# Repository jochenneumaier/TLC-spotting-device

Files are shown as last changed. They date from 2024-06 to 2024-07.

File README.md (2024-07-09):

# TLC-spotting-device
Fully Automated Spotting Device for Thin-Layer Chromatography based on the Modification of a 3D Printer



Column chromatography and the subsequent analysis of the collected fractions using thin-layer chromatography (TLC) are immensely popular and frequently used methods in organic chemistry. To analyze the fractions, they have to be spotted onto the TLC plates, which can be a time-consuming task. Therefore, we have developed an automatic spotting device based on a conversion of a 3D printer kit, which could be easily built for around 500 €. All parts come directly from the 3D printer kit, are 3D printed, or are commercially available, such as syringes and tubing. In this manuscript, we describe the design and use of the spotting device. In addition, we provide a detailed step-by-step assembly instruction and all CAD files for easy replication

The work was published in the Journal of Open Hardware and can be viewed here:

https://doi.org/10.5206/joh.v8i1.18995 

A demonstration video of the TLC spotting device

YouTube (https://www.youtube.com/watch?v=SJwV5dXgm_c)

A detailed assembly instructions can be downloaded here:

https://github.com/jochenneumaier/TLC-spotting-device/blob/c61a826025a51ef96ff2add6b32b9e10538b7a6b/ESI%20-%20Programmable%20Automatic%20Spotting%20Device.pdf

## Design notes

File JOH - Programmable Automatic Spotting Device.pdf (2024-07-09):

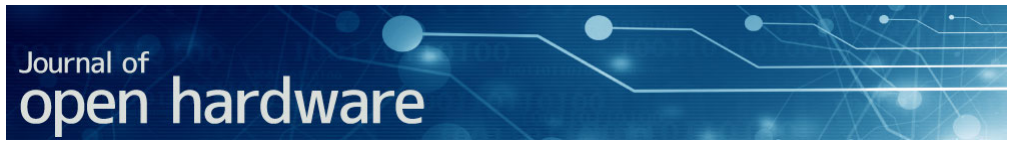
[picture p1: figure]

## Fully Automated Spotting Device for Thin-Layer Chromatography based on the Modification of a 3D Printer

1. Anna-Lena Renz (First author)
ORC ID: 0009-0005-1248-0691
Affiliation: University of Tuebingen, Auf der Morgenstelle 18, 72076 Tuebingen, Germany.
2. Florian Menzel
ORC ID: 0000-0002-1400-549X
Affiliation: Institute of Organic Chemistry, University of Tuebingen, Auf der Morgenstelle 18, 72076 Tuebingen, Germany.
3. Jochen M. Neumaier (corresponding author)
ORC ID: 0000-0002-7996-1490
Affiliation: Institute of Organic Chemistry, University of Tuebingen, Auf der Morgenstelle 18, 72076 Tuebingen, Germany.

## Abstract

Column chromatography and the subsequent analysis of the collected fractions using thin-layer chromatography (TLC) are immensely popular and frequently used methods in organic chemistry. To analyze the fractions, they have to be spotted onto the TLC plates, which can be a time-consuming task. Therefore, we have developed an automatic spotting device based on a conversion of a 3D printer kit, which could be easily built for around 500 €. All parts come directly from the 3D printer kit, are 3D printed, or are commercially available, such as syringes and tubing. In this manuscript, we describe the design and use of the spotting device. In addition, we provide a detailed step-by-step assembly instruction and all CAD files for easy replication.

## Metadata Overview

Main design files: https://doi.org/10.5281/zenodo.12517787
Target group: Scientists and technicians working in chemistry, biochemistry, and associated disciplines.
Skills required: 3D printing – easy; cutting with an angle grinder – easy; mechanical assembly – easy; G-code – easy; Excel usage – easy.
Replication: So far, no replicas have been known to the authors.
See section “Build Details” for more detail.

## Keywords

TLC Spotting; liquid handling; 3D printing; automation; G-code

# (1) Overview

## Introduction

Since thin-layer chromatography (TLC) is a quick, cheap, and sensitive chromatography technique with various post-chromatographic treatment options, it is routinely used in organic chemistry for reaction control and analysis of the fractions acquired after column chromatography.[1, 2] However, to examine the collected fractions a small sample of each fraction must be spotted onto a TLC plate. This task can be very time-consuming, especially as more and more fractions need to be analyzed.
Commercially available spotting devices are quite expensive and usually very inflexible in terms of the size of the rack and the TLC plate.[3] Particularly the usage of different rack sizes can be beneficial, as preparative column chromatography is performed with different amounts of substance and the fractions are collected in vials of different sizes. Therefore, different conditions require different rack sizes and different settings.[2, 3]
There are already several semi-automated and even fully automated devices developed for similar purposes.[4-12] However, most of these devices are designed more for liquid handling operations and do not meet our requirements for spotting TLC plates using flexible rack and TLC plate sizes.
In recent years, there have also been several projects in which low-cost 3D printers have been converted into scientific devices such as syringe pumps or HPLC fraction collectors.[13-16] This has the advantage that no programming or electronics knowledge is required, as the CNC motion control software of the 3D printer is used to control the devices.
We decided to develop a cost-effective, open hardware solution, based on an inexpensive 3D printer (Tronxy X5SA), that can be used with different rack types for TLC spotting. The system can be built for around 500 €. The Tronxy X5SA was chosen because its large print area of 330×330 mm provided the required flexibility for our application. It is also based on a core XY structure, which means that only the extruder moves in the X and Y directions, not the build plate which could have caused spilling. Using primarily the components of the Tronxy X5SA kit or 3D-printed parts, the assembly is fast and straightforward. The necessary G-code files can be easily generated with the attached Excel file, and it enables users to obtain the G-code for different rack sizes and user preferences.
The TLC robot was built to automate the spotting process but could also be used in other liquid handling tasks in the laboratory if the required sequence is programmed in G-code.

## Overall Implementation and Design

### Setup

The basic idea was to keep the assembly of the TLC robot as simple as possible so that anyone with basic manual skills could rebuild it. To achieve that, the design was kept as close to the 3D printer as possible, as can be seen in Figure 1. Originally it was considered to edit the firmware of the 3D printer to change the homing position, for example, but we decided to keep the approach as simple as possible and avoid programming tasks.

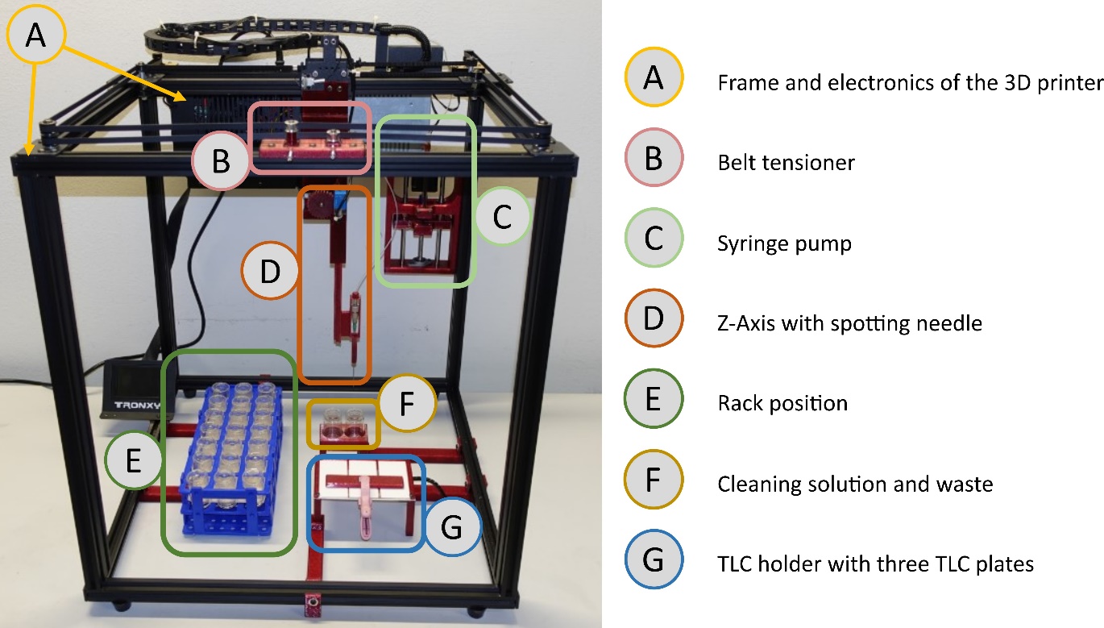
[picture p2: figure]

Figure 1: Overview of the Spotting Device.
Movement in the X and Y directions is ensured by the 3D printer's almost unchanged CoreXY system. Only a belt tensioner (B) has been added so that the tension can be adjusted after assembly. The movement of the capillary in Z-direction on the other hand is facilitated by a gear wheel and gear rack to which the cannula is attached (D). The syringe pump at the rear of the TLC robot (C) enables defined quantities of liquid to be dispensed.
To be able to clean the cannula, two glasses (diameter: 3 cm, height: 5 cm) are placed inside the table at the back (F), one filled with cleaning solution and one empty for the waste. The required number of TLC plates (4×8 cm) can be positioned on the TLC holder (G) and fixed with a clamp to maintain their position throughout the spotting process. The rack with the collected fractions (E) can be inserted on the left side. Its position is determined by aligning it with three positioners.
The various G-code programs can be created with the Excel file and stored on the SD card of the 3D printer. If the SD card is inserted into the Host box, the different programs can be selected on the display on the left side of the base frame.
As the system is modular, the different parts can easily be replaced with alternatives, allowing further customization. For example, the two tables can easily be replaced by slightly different variants if glasses or TLC plates with different dimensions are used.

### Motion in Z-Direction

In order to avoid prolonging the spotting process unreasonably, the capillary should be able to move in Z-direction at approximately the same velocity as in X- and Y-direction. Initially, a design with one lead screw and two guide rails (similar to the design of the syringe pump) was considered. However, the maximum velocity achievable with this design proved to be too low during the test. Therefore, this approach was replaced by the current design consisting of a gear wheel connected to the shaft of one NEMA motor and a gear rack inside a guiding rail to achieve the required speed (Figure 2). The size of the gear wheel was adjusted so that the capillary could move safely above all objects during the homing process.

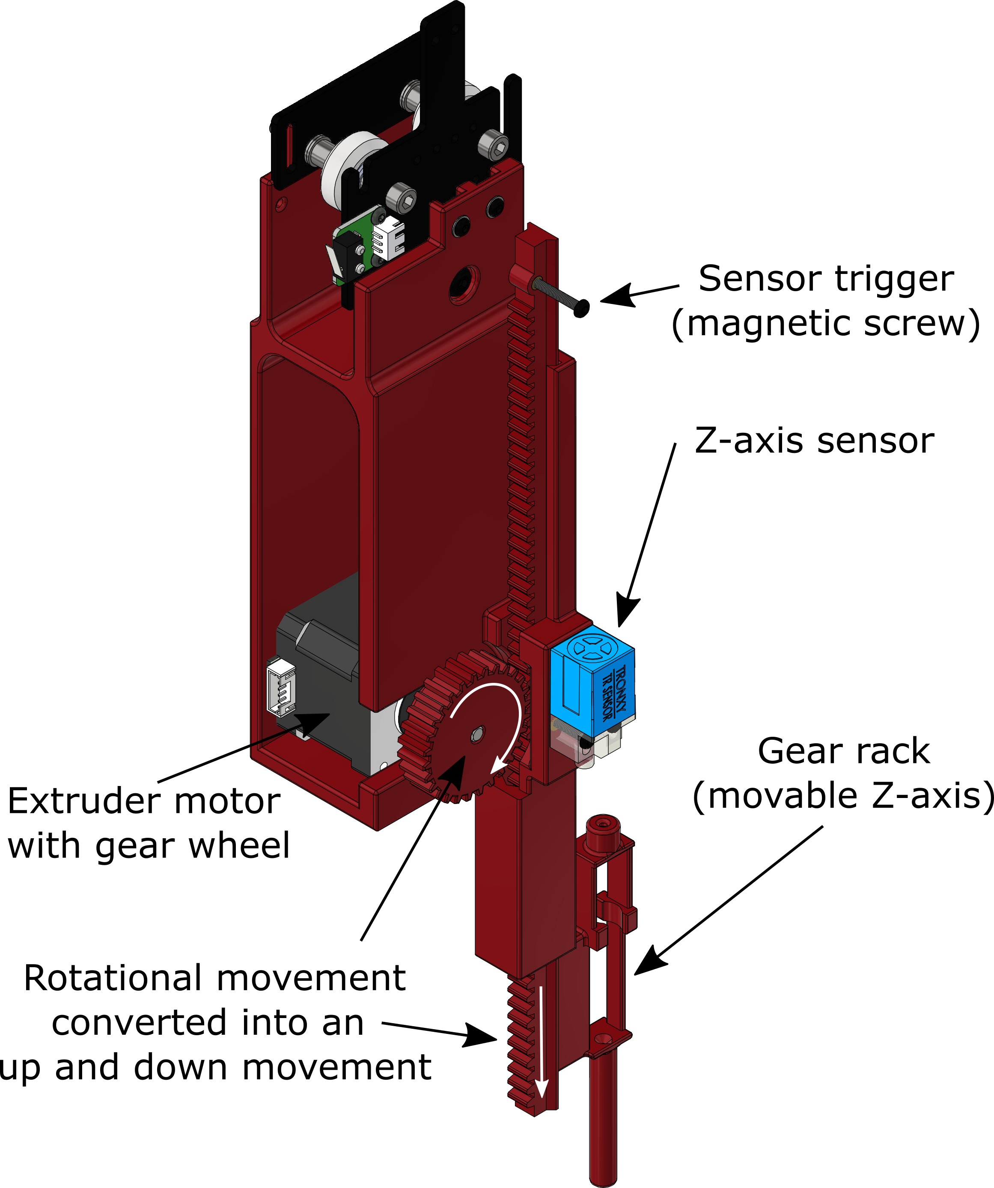
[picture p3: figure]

Figure 2: CAD drawing of the Z-axis mounting [17-20].

### Capillary Holder with Spring Mechanism

A standard medical cannula (Braun Sterican, 21G) was inserted into the rack, which represents the actual movable Z-axis (Figure 3). As the tip of the cannula must not be sharp, it was cut off and smoothed. A reasonably long capillary was used to ensure a long travel distance that is required to collect samples from vials with different fluid levels. To avoid the adhesion of a large fluid droplet to the outside of the cannula, a cannula with a small diameter (21G, 0.72mm) was used. As the cannula is in contact with the TLC plates during spotting, a spring mechanism was included to avoid scratching the surface of the TLC plates. This mechanism ensures that the cannula can move slightly upwards when it hits the TLC plate to provide even and gentle contact pressure and to compensate for any unevenness. The fixation was introduced to avoid rotation of the cannula. It is important to ensure that the connection with the fixation does not block the up- and downward movement of the cannula.

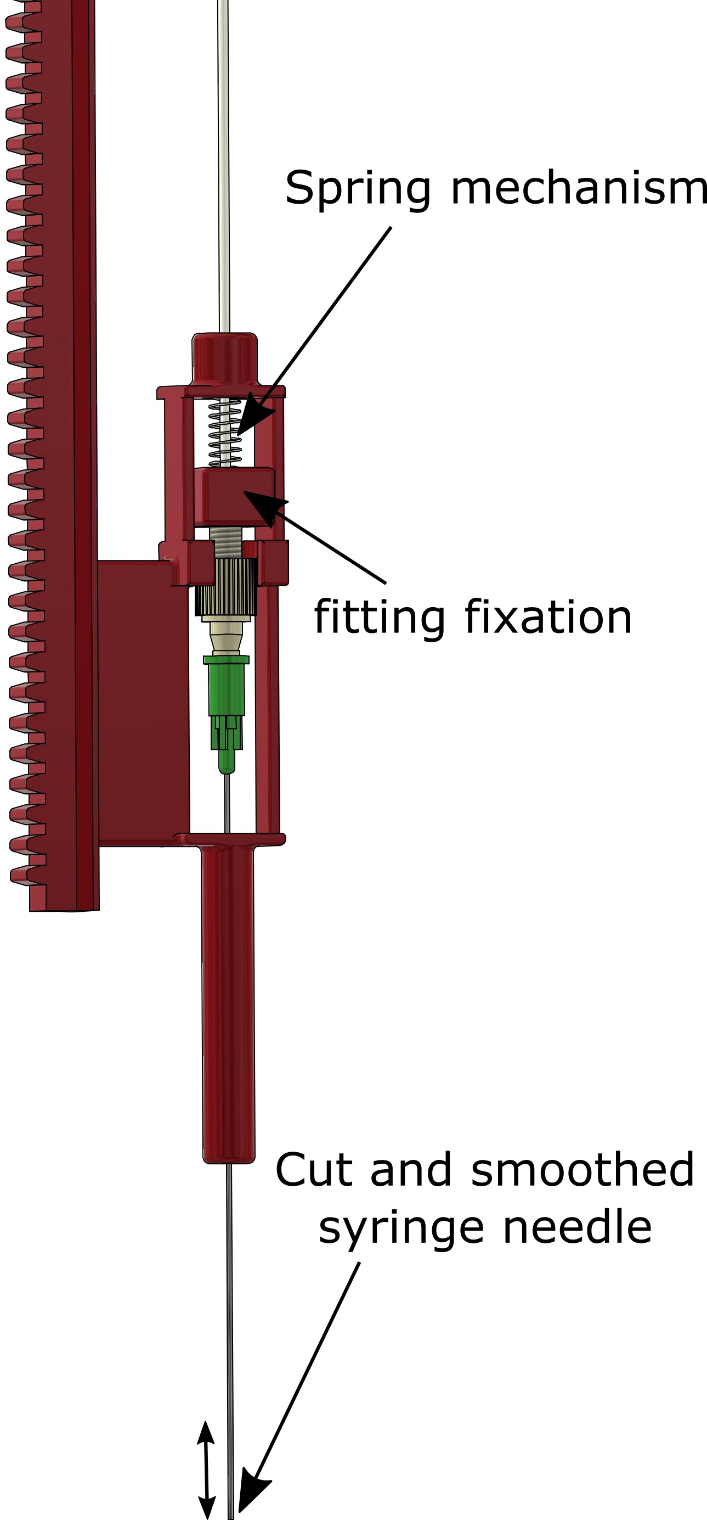
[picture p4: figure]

Figure 3: CAD drawing of the capillary holder with spring mechanism.

### Syringe Pump

The syringe pump was designed in a way that it is possible to collect and transport defined volumes from 1 µl to 1 mL. It is based on two guide rails and a lead screw (Figure 4), which both originally came from the 3D printer kit, and were shortened to the appropriate length (see ESI on Zenodo/GitHub). As syringe, a 1 mL Gastight Syringe (Model 1001 TLL from Hamilton) was chosen. The pump must be placed upright so that any air inclusions are expelled during the flushing process.

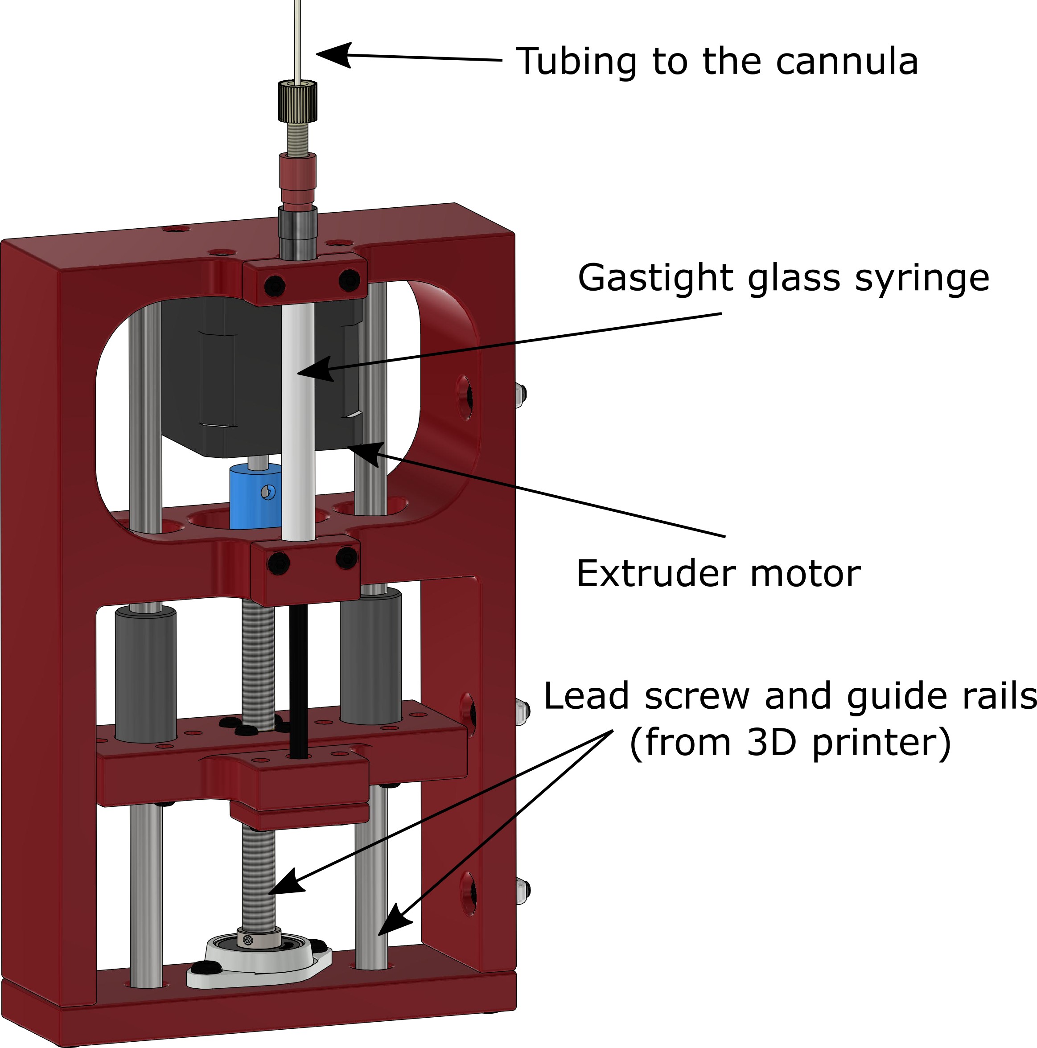
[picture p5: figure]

Figure 4: CAD drawing of the syringe pump.

### TLC Holder

To keep the TLC plates in place, a table based on an aluminium plate and a 3D-printed frame was used (Figure 5). As the size of our TLC plates (Machery Nagel POLYGRAM® SIL G/UV254, 40×80 mm) varied by 3 mm, a frame with small separators ensures that the plates remain in the same position during the spotting process. If larger TLC plates need to be used, the separators must either be cut off or removed in the CAD file before printing.

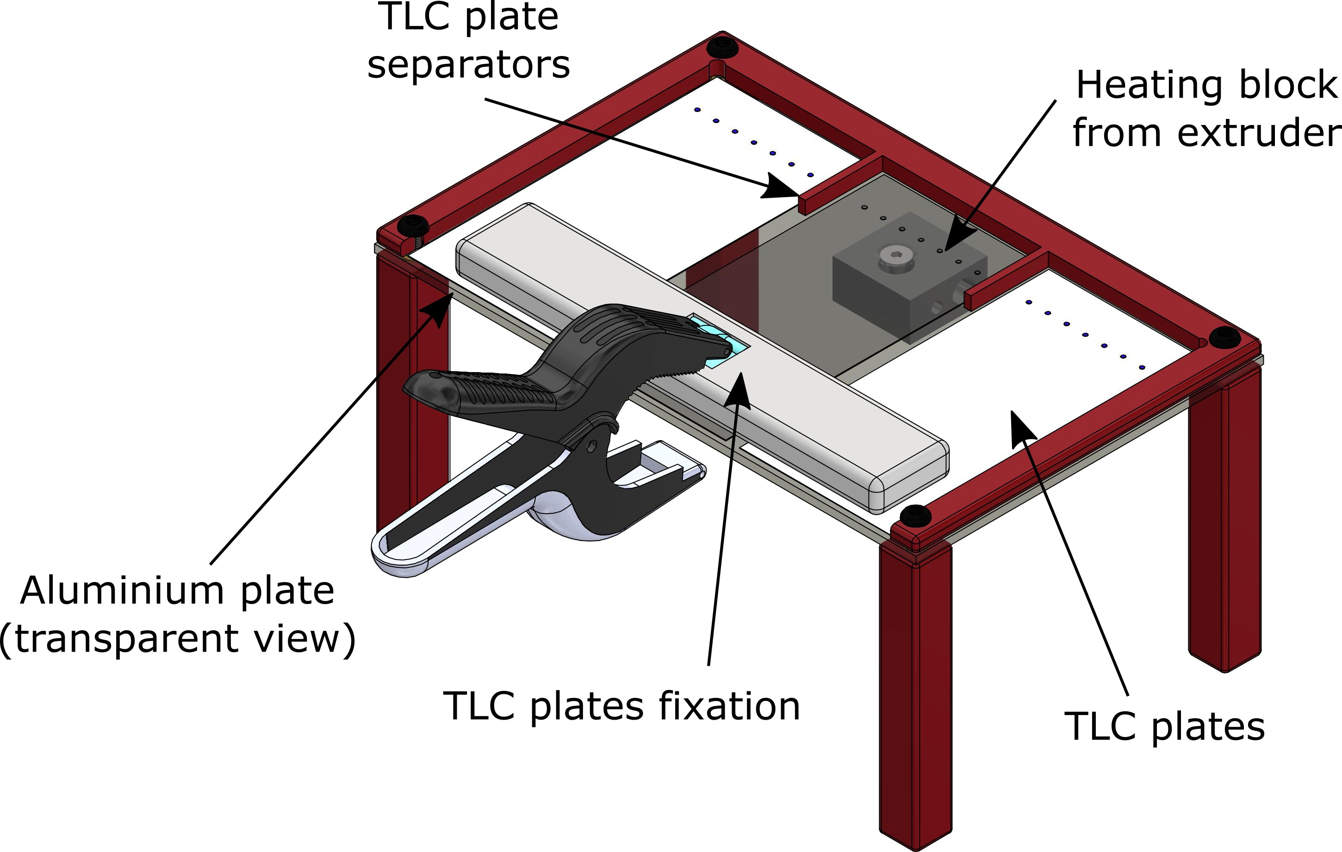
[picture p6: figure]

Figure 5: CAD drawing of the TLC holder [21].
To speed up the spotting process, the heating block from the 3D printer was connected to the bottom of the aluminum plate. The TLC plates are thus heated during the spotting process, which leads to faster evaporation of the solvent. This is particularly useful when high-boiling solvents such as water, toluene, or dimethyl sulfoxide (DMSO) are used. A spring clamp in combination with a 3D-printed extended end was used to hold the TLC plates in place.

### Belt Tensioner

As the tension of the tension belts decreased over time and the movement of the TLC robot became less and less precise, a belt tensioner was introduced. The belt tensioner was taken from an existing design without any modifications.[22]

# (2) Quality Control

## Safety

Entanglement or entrapment in moving parts: Since the cannula moves abruptly and fast in all three directions during the process, tasks inside the base frame should be avoided while the TLC robot is running. If a problem occurs during a run of the TLC robot, the run should always be stopped first before any adjustments inside the base frame are made. The host box at the back left corner allows the operator to stop each program instantly by turning off the power while staying away from moving parts.

Risks of burning fingers while inserting or removing the TLC plates: Since the aluminum plate of the TLC holder is heated up during the spotting process, the operator can slightly burn their fingers while changing the TLC plates. To minimize the risk of burning, the maximum temperature selectable for the heating block was limited in the Excel file to 70 °C and the default value was set to 50 °C. Furthermore, the heating is stopped after the last spot is made. Therefore, the heated elements can already cool down while the spotting program is finished.

Electric shock: As with any other electrical device, there is a risk of electric shock. However, only the power supply of the host box is operated with main voltage (230 V). The other cables, which only have a voltage of 48 V, are covered and permanently installed. Nevertheless, all cables should be checked for damage before operating the robot and replaced if necessary.

Chemical exposure: When working with volatile solvents or other hazardous substances, appropriate safety precautions must be taken, e.g. placing the device in a fume hood.

## Calibration

Before using the TLC robot for the first time, a calibration is required. These procedures are described in detail in the ESI on Zenodo/GitHub and summarized below. Once the calibration is complete, recalibration is only required if the syringe in the syringe pump is replaced, the positioners that ensure that the objects are always in the same position are moved in X or Y direction, or if a new rack is inserted.

### Calibration of the Syringe

To calculate the correct number of E units required to draw and dab a given volume, three parameters must be determined: the nominal volume of the syringe in the syringe pump, the residual volume in the syringe in its zero position and the E value required to fill the syringe to its nominal value.

### Determination of all Coordinates

To generate the correct G-code, the coordinates of all components must be determined and entered in the Excel file. In case of the TLC holder, the waste bin, and the cleaning solution the X-, Y- and Z-values of one specific position have to be determined, as well as the corresponding height for movement between these parts. For each rack size on the other hand, it is necessary to determine the x- and ycoordinates of two vials in diagonally opposite corners, which enables the positions of the other vials to be calculated. Furthermore, the corresponding Z-values for the fluid collection and movement above the rack have to be determined.

### Generation of the G-Code Programs

The G-code can be generated with the provided Excel file. At least one G-code program per rack is required to use each rack with the TLC robot. However, is possible to create different programs for each rack to fulfill different user preferences.
To do so, first, all parameters obtained during the calibration process must be entered. Subsequently, the user can implement their preferences to the program. The G-code file must be exported and saved on an SD card that can be inserted into the host box. The new program can be selected on the display of the TLC robot.

## General Testing

The spotting robot has been in use for about a year, on average at least 10–20 times a week. During this time, there have been a few minor issues that have been resolved easily.
- The belt tension decreased, resulting in imprecise movement in X and Y directions. As a result, a belt tensioner was introduced, as mentioned above.
- The cannula was able to rotate freely during the spotting process, which led to imprecise spotting points with a slightly bent cannula. A fixation was therefore introduced, as can be seen in Figure 3. This prevents rotation and precise spotting points are achieved even with a slightly bent cannula.

The TLC spotting robot has been extensively tested with two different rack types, one 3×7 rack (size 26.5×12.5 cm) and one 4×7 rack (size 23×16 cm) with snap lid jars or tubes with a diameter of 3 cm. These are our standard collection vials for column chromatography. During the tests, the racks have been filled with vials with a height of either 5 cm (small), 10 cm (middle), or 20 cm (large). Smaller test tubes with a diameter of 15 mm were also successfully tested.
With the current settings, it is possible to use the TLC robot for racks with a size of up to 32×19 cm. It may also be possible to use a larger rack. This would require changing the homing positions in the firmware and rearranging all other components.
The maximum possible height of a rack with the vials inside is 21 cm. If higher racks are required, the length of the Z-axis mounting has to be shortened in the CAD software. The height of the two tables (TLC and washing table) has to be changed accordingly.
With the current settings, the capillary can only be lowered down to approximately 5.5 cm above the bottom. Therefore, if the height of the rack is smaller than 7 cm, it should be elevated for example, by a lifting platform until a height of approximately 10 cm.

In order to check whether the spotting process leads to carry-over into subsequent spots, an experiment with two different concentrations of a Nile red solution was carried out. After each vial with Nile red solution, several vials filled with pure solvent (acetone) were spotted and visually examined to see whether carryover occurred (Figure 6).

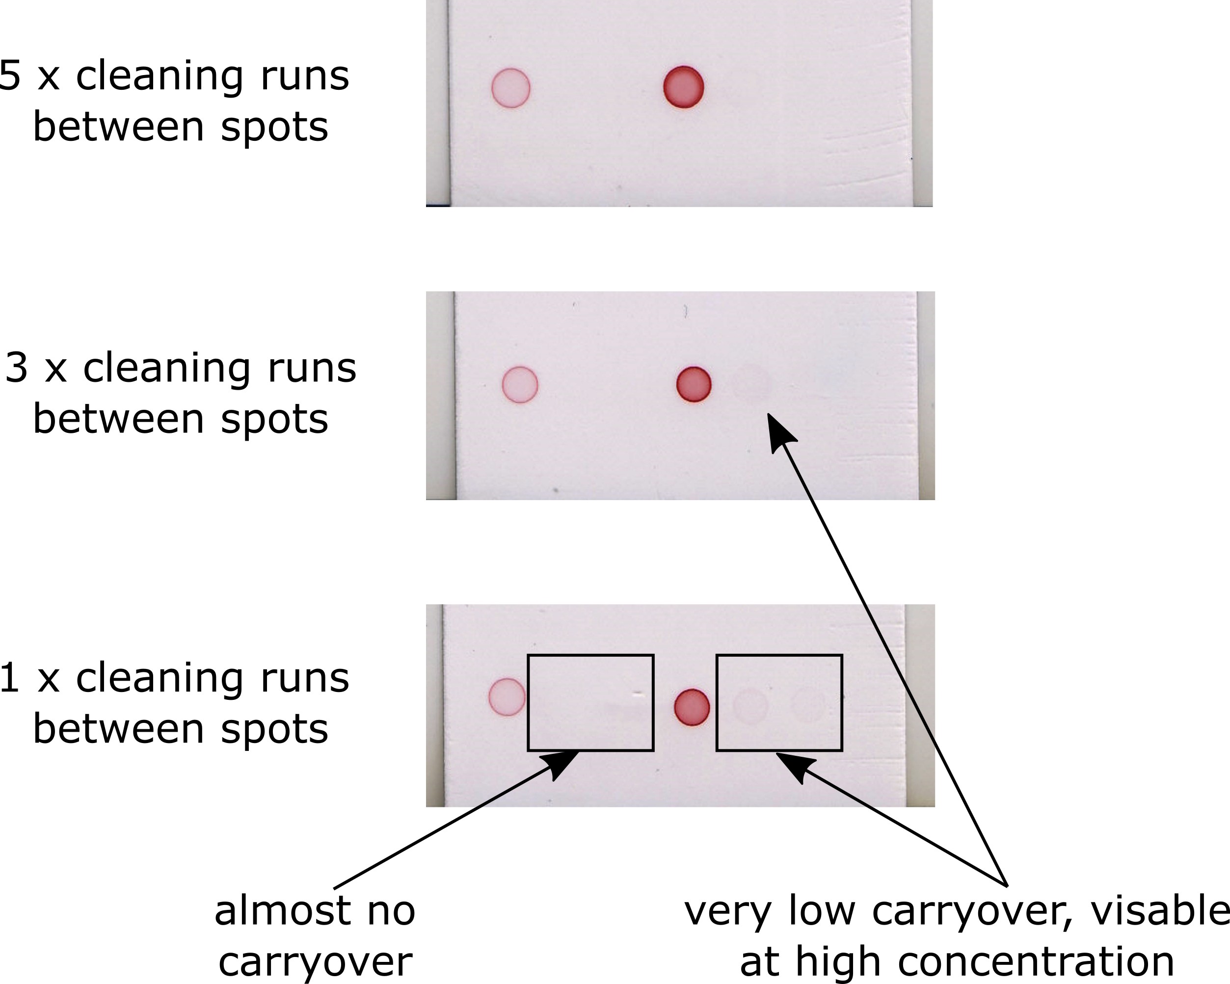
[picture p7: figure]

Figure 6: Overview of the complete process.

During the experiment, the cannula was automatically cleaned before entering a new vial. The number of times the cleaning process was run each time was gradually increased from 1 to 5. With 5 cleaning runs between spotting, almost no carryover was seen even at high concentrations. With a single cleaning run, very low carryover, which was only visible at very high concentrations (saturated solution), was observed. For the application as a spotting device for TLC, a single run cycle between the spots is sufficient. This can significantly reduce the duration of the whole spotting process. A whole spotting process of our standard racks (3×7 jars) during column chromatography takes approximately 7 minutes.

# (3) Application

## Use Case

We only used the TLC spotting device for the application of spotting TLCs. Figure 7 gives an overview of standard column chromatography followed by automatic spotting on the TLC plates and the development of those plates. A video showing the TLC robot in action can be found here.

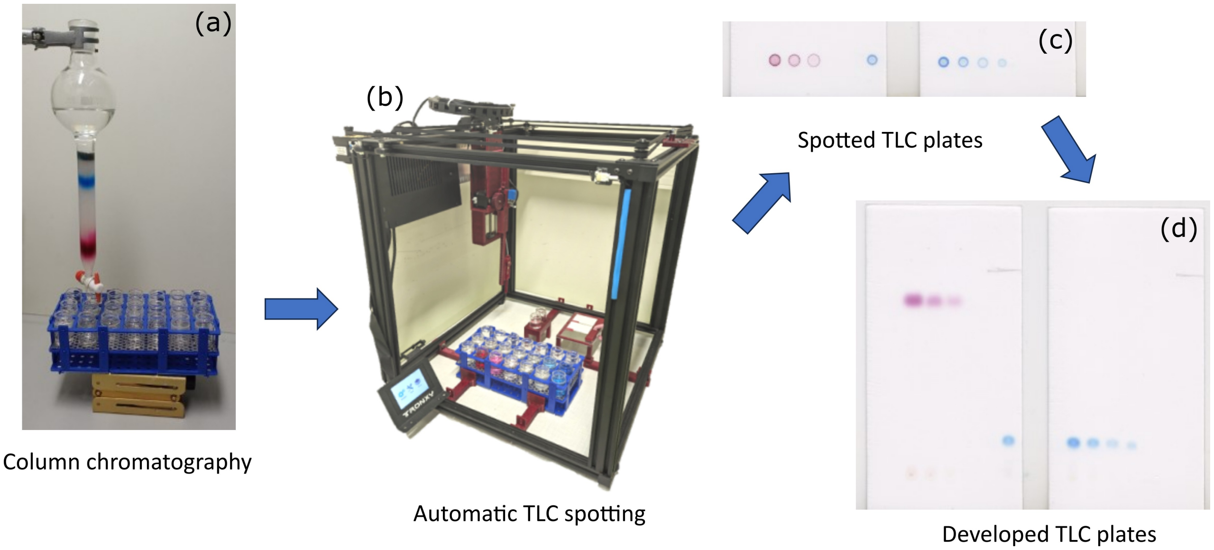
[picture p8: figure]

Figure 7: Overview of the complete process.
In this example, a manual preparative column chromatography was first carried out with a dye mixture of Sudan Red 7B and Oil Blue 35. The fractions were collected in a 3×7 rack (Figure 7a). For this rack, a G-code program with 3 applications per spot was created in Excel and executed with the TLC robot (Figure 7b). The TLC plates spotted in this way (Figure 7c) were developed using toluene as the mobile phase (Figure 7d).

### Reuse Potential and Adaptability

Since we designed the TLC robot to be as flexible as possible, it is possible to create a G-code for almost any type of rack and TLC plates for spotting. The TLC robot could also be used for other liquid handling tasks, e.g., transferring reagents from different containers to one or more reaction vessels. This, for example, could be useful for reaction screening in parallel synthesis.[23, 24] Therefore, some changes are required: Some new positioners would need to be printed calibrated. The Excel file would have to be adapted to generate a matching G-code.

The device could also be used for biological tests where 96-well plates are used, such as ELISA assays.[25] We tested the precision of the TLC robot with a 96-well plate as a rack and found no problems with precision during the run.
Another application of the TLC robot could be the usage for quantitative TLC, as a precise and adjustable amount of solution is always spotted onto the TLC.[26-28] Dilution series of different substances would have to be examined and calibration curves have to be created to see whether the accuracy of the extruding syringe is sufficient for this application.

# (4) Build Details

## Availability of Materials and Methods

Most of the components were either part of the Tronxy X5SA kit or were produced using 3D Printing, the STL- and STEP-files can be found on Zenodo/GitHub. The other materials are readily available from online suppliers. A complete material list, including URLs of suppliers, is included in the ESI file on Zenodo/GitHub. The TLC robot can be assembled using normal tools. An angle grinder is recommended to cut the slide rods to the correct length and a bench drill with a vice to drill accurate holes in the aluminum plate. A 3D printer with a print area of at least 300×250 mm is also required to print the rather large components. As printing material PETG was used due its prior temperature, chemical and impact resistance. If PLA is used as printing material it is necessary to ensure that the maximum temperature of the heating block is limited to 50 °C. A detailed step-by-step instruction with sample photos and CAD drawings of the components can be found in the ESI file on Zenodo/GitHub.

## Ease of Build / Design Decision

The general idea was to keep building the TLC robot as easy as possible. Therefore, it was opted to not shorten the vertical aluminum profiles but to print a longer casing of the Z-axis mounting instead. Changes in the electronic set-up were kept to a minimum and only require plugging and unplugging of cables and pins. Changes in the firmware were avoided. The TLC robot can be easily built and calibrated within around 2 days.

## Operating Software and Peripherals

The original CNC motion control software of the 3D printer is used for controlling the processes of the TLC robot. The necessary G-code can be generated with the provided Excel file. However, Excel 2010 or a newer version is required for using our file. For the calibration process, any slicer software with a machine control panel, e.g., Cura, Simplify3D, can be used.

## Hardware Documentation / Build Instructions / Files Location:

Name: Zenodo/GitHub: TLC spotting device
Persistent identifier: https://doi.org/10.5281/zenodo.12517787
Publisher: Jochen M. Neumaier
Date published: 2024-06-24

# (5) Discussion

## Conclusions

In this paper, we have described a programmable fully automated spotting device that is capable of performing a spotting process for thin-layer chromatography. Primarily, this robot was developed to automate and simplify the TLC spotting process after column chromatography. Due to the flexible design, almost all types of racks and TLC plates can be used. This device was built using a 3D Printer Kit and mainly 3D-printed parts for a total cost of around 500 €.
Due to the many setting options, e.g., number and velocity of spotting operations, pause between spotting, or heating of the TLC plates, it is possible to apply relatively large volumes on the TLC plates and still obtain spots with relatively small diameters and good accuracy.
Furthermore, under the same settings, the TLC robot should be able to reproduce more reproducible results than a human operator.

## Future Work

The current version of the TLC robot is fully functional and fulfills its tasks reliably. Nevertheless, some further improvements could be considered in the future:
For ease of use, an Excel file was used to generate the G-code. However, it would be conceivable to adapt the program to an open-source version such as OpenOffice or LibreOffice, so that no Excel license would be required, and the replication of the TLC robot would be easier. If necessary, the settings in the firmware could be changed so, that, for example, the homing position could be altered. This allows the various components to be placed closer together or larger racks to be inserted into the frame.

## Funding Statement

We thank the Karl und Anna Buck Stiftung for funding this work.

## Competing Interests

The authors declare that they have no competing interests.

## References

[1] Cai, L. 2014. Thin Layer Chromatography. Current Protocols Essential Laboratory Techniques 8 (1): 6.3.1-6.3.18. https://doi.org/10.1002/9780470089941.et0603s08
[2] Poole, C.F. 2003. Thin-layer chromatography: challenges and opportunities. J. Chromatogr. A 1000 (1): 963-984. https://doi.org/10.1016/S0021-9673(03)00435-7
[3] Bernard-Savary, P., Poole, C.F. 2015. Instrument platforms for thin-layer chromatography. J. Chromatogr. A 1421 184-202. https://doi.org/10.1016/j.chroma.2015.08.002
[4] Xu, H., Zhang, D. and Mo, F. 2022. High-throughput automated platform for thin layer
chromatography | analysis. | STAR | Protocols | 3 | (4): | 101893.
https://doi.org/10.1016/j.xpro.2022.101893
[5] Barthels, F., Barthels, U., Schwickert, M. and Schirmeister, T. 2020. FINDUS: An Open-Source 3D Printable Liquid-Handling Workstation for Laboratory Automation in Life Sciences. SLAS Technology 25 (2): 190-199. https://doi.org/10.1177/2472630319877374

[6] Zhang, C., Wijnen, B. and Pearce, J.M. 2016. Open-Source 3-D Platform for Low-Cost
Scientific | Instrument | Ecosystem. | SLAS | Technology | 21 | (4): | 517-525.
https://doi.org/10.1177/2211068215624406
[7] Medina, D.A.V., Rodriguez Cabal, L.F., Lanças, F.M. and Santos-Neto, Á.J. 2019. Sample treatment platform for automated integration of microextraction techniques and liquid chromatography analysis. HardwareX 5 e00056. https://doi.org/10.1016/j.ohx.2019.e00056
[8] Florian, D.C., Odziomek, M., Ock, C.L., Chen, H. and Guelcher, S.A. 2020. Principles of computer-controlled linear motion applied to an open-source affordable liquid handler for automated micropipetting. Scientific Reports 10 (1): 13663. https://doi.org/10.1038/s41598-020-70465-5
[9] Keesey, R., LeSuer, R. and Schrier, J. 2022. Sidekick: A Low-Cost Open-Source 3D-printed liquid dispensing robot. HardwareX 12 e00319. https://doi.org/10.1016/j.ohx.2022.e00319
[10] Sing, L., Schwack, W., Göttsche, R. and Morlock, G.E. 2022. 2LabsToGo─Recipe for Building Your Own Chromatography Equipment Including Biological Assay and Effect Detection. Anal. Chem. 94 (42): 14554-14564. https://doi.org/10.1021/acs.analchem.2c02339
[11] Fichou, D., Morlock, G.E. 2018. Office Chromatography: Miniaturized All-in-One Open-Source System for Planar Chromatography. Anal. Chem. 90 (21): 12647-12654. https://doi.org/10.1021/acs.analchem.8b02866
[12] Ouyang, W., Bowman, R.W., Wang, H., Bumke, K.E., Collins, J.T., Spjuth, O., Carreras-Puigvert, J. and Diederich, B. 2022. An Open-Source Modular Framework for Automated
Pipetting | and | Imaging | Applications. | Advanced | Biology | 6 | (4): | 2101063.
https://doi.org/10.1002/adbi.202101063
[13] Baas, S., Saggiomo, V. 2021. Ender3 3D printer kit transformed into open, programmable syringe pump set. HardwareX 10 e00219. https://doi.org/10.1016/j.ohx.2021.e00219
[14] Carvalho, M.C., Oakes, J.M. 2023. Turning a 3D Printer into a HPLC Fraction Collector: A Tool for Compound-Specific Stable Isotope Measurements. Hardware 1 (1): 29-53. https://doi.org/10.3390/hardware1010004
[15] Ponzetti, M., Chinna Rao Devarapu, G., Rucci, N., Carlone, A. and Saggiomo, V. 2022. HistoEnder: A 3D printer-based histological slide autostainer that retains 3D printer functions. HardwareX 12 e00370. https://doi.org/10.1016/j.ohx.2022.e00370
[16] Mason, A.F., Wickham, S.F. and Baker, M.A. 2024. DIB-BOT: An open-source hardware approach for high throughput droplet interface bilayer deposition. bioRxiv 2024.2001.2026.577347. https://doi.org/10.1101/2024.01.26.577347
[17] | Tronxy | X5SA | hotend | carriage: | Adapted | from | | Florovskiy, | 2021:
https://grabcad.com/library/tronxy-x5sa-hotend-carriage-1 (checked 11.03.2024).
[18] X-axis switch: Adapted from Maxfield, 2021: https://grabcad.com/library/creality-limitswitch-z-stop-1 (checked 11.03.2024).
[19] | Tronxy | X5SA | Pro | 330x330: | Adapted | from | H. | Schmidt, | 2021:
https://grabcad.com/library/tronxy-x5sa-pro-330x330-1 (checked 11.03.2024).
[20] Z-axis sensor: Adapted from D. Stoianovici, 2021: https://grabcad.com/library/tronxytr-sensor-1/details?folder_id=12291083 (checked 11.03.2024).
[21] Spring Clamp: Adapted from A. Bieber, 2016: https://grabcad.com/library/springclamp-4 (checked 11.03.2024).
[22] CoreXY Belt Tensioner Update v.2: Adapted from H. Schmidt, 2021: https://grabcad.com/library/corexy-belt-tensioner-update-v-2-1 (checked 11.03.2024).
[23] Powers, D.G., Coffen, D.L. 1999. Convergent automated parallel synthesis. Drug Discovery Today 4 (8): 377-383. https://doi.org/10.1016/S1359-6446(99)01364-1
[24] Collins, K.D., Glorius, F. 2013. A robustness screen for the rapid assessment of chemical reactions. Nature Chemistry 5 (7): 597-601. https://doi.org/10.1038/nchem.1669
[25] Aydin, S. 2015. A short history, principles, and types of ELISA, and our laboratory experience
with | peptide/protein | analyses | using | ELISA. | Peptides | 72 | 4-15.
https://doi.org/10.1016/j.peptides.2015.04.012
[26] Sowers, M.E., Ambrose, R., Bethea, E., Harmon, C. and Jenkins, D. 2022. Quantitative thin layer chromatography for the determination of medroxyprogesterone acetate using a smartphone and open-source image analysis. J. Chromatogr. A 1669 462942. https://doi.org/10.1016/j.chroma.2022.462942
[27] Askal, H.F., Khedr, A.S., Darwish, I.A. and Mahmoud, R.M. 2008. Quantitative thin-layer chromatographic method for determination of amantadine hydrochloride. Int J Biomed Sci 4 (2): 155-160. https://doi.org/10.59566/IJBS.2008.4155
[28] Wadie, M., Abdel-Moety, E.M., Rezk, M.R. and Marzouk, H.M. 2023. A novel smartphone HPTLC assaying platform versus traditional densitometric method for simultaneous quantification of alfuzosin and solifenacin in their dosage forms as well as monitoring content uniformity and drug residues on the manufacturing equipment. RSC Advances 13 (17): 11642-11651. https://doi.org/10.1039/D3RA01211E

# (6) Licenses

Article and hardware: CC-BY 4.0. See: https://creativecommons.org/share-your-work/cclicenses/

## Copyright notice

Authors who publish in this journal agree to the following terms:

Authors retain copyright and grant the journal right of first publication with the work simultaneously licensed under a Creative Commons Attribution License that allows others to share the work with an acknowledgment of the work's authorship and initial publication in this journal.

Authors can enter into separate, additional contractual arrangements for the non-exclusive distribution of the journal's published version of the work (e.g., post it to an institutional repository or publish it in a book), with an acknowledgment of its initial publication in this journal.

By submitting this paper you agree to the terms of this Copyright Notice, which will apply to this submission if and when this journal publishes it.

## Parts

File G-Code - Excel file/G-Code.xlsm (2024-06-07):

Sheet: read_me
worksheet | function
read_me | This Excel file can generate the relevant g-code files for the TLC robot if a decimal point is selected as the decimal separator in the operating system and in Excel. If all macros are activated, the only the three buttons in this worksheet are required to generate all relevant g-code files, as clicking on them opens different user interfaces. After clicking the "Modify g-code" button, several parameters can be changed, for example, to generate the g-code for different rack sizes. If the "Advanced Settings" button is clicked, a new set-up for the TLC robot can be calibrated. Finally, the g-code files can be exported after clicking the button "Export g-code". If macros are deactivated, the parameters can be changed in the worksheet "modify" and "initialize" and the g-code can be copied from the worksheets "export" and "calc3".
modify | The parameters in this worksheet can be changed to adapt the g-code to different rack sizes or different user preferences.
initialize | The parameters in this worksheet can be changed to adapt the g-code to new set-ups. After the initial calibration, these parameters only have to be altered if the set-up is changed.
calc1 | The parameters in this file are calculated from other parameters. Therefore, they should only be changed if the basic structure of the g-code has to be changed.
calc2 | This file contains short g-code segments that are used to generate the g-code in the files "calc3" and "export".
calc3 | In this worksheet, the g-code for the individual steps of the sampling program is calculated. Modifications should only be made if the basic structure of the g-code has to be changed.
export | The g-code for different processes is calculated in this file. Modifications should only be made if the basic structure of the g-code has to be changed. To create a new g-code file without macros, copy the relevant cells into a new editor file, remove the quotation marks, and save the file as ".gcode".
labels | This files contains the names of all parameters used in the user interfaces and their references to cells in the Excel file. If cells are moved in the file, this list can help to reset the correct references.

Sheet: modify
rack |  | TLC |  | spotting |  | cleaning
type of rack | 7x4 rack with medium tubes | number of TLC plates that are used | 3 | volume extruded on TLC per spot (μL) | 3.00 | cleaning after (1=each collected sample, 2=each second, etc.) | 1.00
sampling order | s-shape, starting at back left corner | Heating of the TLC plates during the spotting programm? | TRUE | number of extrusions per spot | 10 | number of repeats of the cleaning process between two samples | 1.00
 |  | temperature of the extrudor that heats up the metal plate (°C) | 50 | velocity to empty the syringe during spotting | 25.00 | number of cleaning processes before the sampling process | 2.00
 |  | Include washing program in spotting program? | TRUE | time between extrusions on the same spot (s) | 1.00 | number of additional cleaning processes at the end of the process | 2.00
sampling of (1=each sample, 2=each second sample, etc.) | 1 | Acoustic signal once the spotting progam is finished? | TRUE
number of samples that are collected in test of sampling program | 7

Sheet: initialize
name of each rack | number of samples |  | sample in back left corner |  | sample front right corner |  | z-value for |  | positions | x | y | z | TLC |  | spotting |  | velocitys (units/s) |  |  | max. feedrate (units/s) | max. acceleration (units/s2)
 | long side (y-direction) | short side (x-direction) | x | y | x | y | sampling | movement above all items | cleaning solution | 191.00 | 212.00 | 0.05 | width of one TLC plate (mm) | 40.00 | volume that is additionally retracted & extruded back into the sample to compensate clearance between components (E-units) | 5.00 | velocity in x- & y-direction | 20000.00 | E | 10000.00 | 2000.00
7x3 rack with small/ medium tubes | 7 | 3 | 5 | 294 | 85 | 70 | 0.05 | 4 | waste bin | 226.00 | 212.00 | 2.00 | distance between spotting points and back edge of a TLC plate (mm) | 15.00 | time on spot after each extrusion (ms) | 300.00 | velocity in z-direction | 500.00 | X & Y | 20000.00 | 2000.00
7x3 rack with large tubes | 7 | 3 | 5 | 294 | 85 | 70 | 6.2 | 10 | calibration point (Screw in the front left corner of the TLC holder) | 175.80 | 59.00 | 0.90 | distance to TLC plates at which velocity is decreased (z-units) | 1.00 | volume that is additionally retracted in sampled & extruded into the waste bin (E units) | 5.00 | reduced velocity in z-direction for spotting on TLC plates | 100.00 | Z | 10000.00 | 200.00
7x4 rack with large tubes | 7 | 4 | 0 | 295 | 121.5 | 102 | 6.2 | 10 | parking position of the z-axis | 250.00 | 330.00 | 0.05 |  |  | waiting time above waste bin after extrusion (ms) | 300.00 | velocity to fill the syringe during the washing program | 900.00
7x4 rack with medium tubes | 7 | 4 | 0 | 295 | 121,5 | 102 | 0,05 | 3,5 | min. height for movement above TLC holder, cleaning solution & waste bin | - | - | 3.50 | syringe |  | factor that the retraction in the samples is multiplied with to calculate the retraction in the cleaning solution | 1.50 | velocity to empty the syringe during the washing program | 10000.00
 |  |  |  |  |  |  |  |  |  |  |  |  | residual volume in the syringe when the middle part of the syringe pump is touching the top part (mL) | 0.05 |  |  | velocity to empty the syringe | 2500.00
 |  |  |  |  |  |  |  |  |  |  |  |  | nominal volume of the syringe (mL) | 1.00 | washing program |  | velocity to fill the syringe in the samples & in the cleaning solution | 500.00
 |  |  |  |  |  |  |  |  |  |  |  |  | E-value needed to fill the syringe up to the end of the scale (relative E units) | -248.00 | waiting time to fill syringe during washing program (s) | 1.00
 |  |  |  |  |  |  |  |  |  |  |  |  |  |  | number of repeats during the washing program | 3

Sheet: calc1
extrusion |  | TLC |  | rack |  | options for sampling order |  | number of samples |  | sample in back left corner |  | sample front right corner |  | z-value for |  | options for boolean values
extruded volume per 1E unit (mL) | 0.003830645161 | distance between two TLC plates (mm) | 2.687 | number of samples in rack | 28 | s-shape, starting at back left corner |  | long side (x-direction) | short side (y-direction) | x | y | x | y | sampling | movement above all items | TRUE
retraction in sample (to fill syringe) (E units) | -10.783 | number of spots on the first TLC plate | 10 | number of collected samples | 28 | s-shape, starting at front left corner | selected rack | 7 | 4 | 0 | 295 | 121.5 | 102 | 0.05 | 3.5 | FALSE
extrusion on TLC per spot (E units) | 0.0783 | number of spots on the second TLC plate | 9 | distance between two samples in the rack in x-direction | -32.16666667 | non alternating, starting at back left corner
retraction in cleaning solution (E units) | -16.1745 | number of spots on the third TLC plate | 9 | distance between two samples in the rack in y-direction | 40.5 | non alternating, starting at front left corner |  | x | y | z
max. value of the factor that is used to calculate the retraction in cleaning solution | 23 |  |  |  |  |  | back right corner of TLC plate on the right | 301.00 | 137.00 | 0.35
max. value of extraction in sample | 12.61904762

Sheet: calc2
start1 | start 2 | stop1 | stop2
G0 Z3,5 F500 | M201 E2000 X2000 Y2000 Z200 ; increase max. acceleration M203 E10000 X20000 Y20000 Z10000 ; increase max. feedrate G90 ; absolute positioning M83 ; put E axis into relative mode G28 ; homing | G0 Z3,5 F500 G0 X250 Y330 F20000 ; move to parking position G0 Z0,05 F500 | G4 S1 ; waiting time to prevent abortion of the printing process G4 S1 G4 S1 G4 S1 G4 S1 G4 S1 G4 S1 G4 S1
retraction | extrusion | waste1
; sampling G0 E-10,783 F500 ; extrusion in sample G0 E5 F500 ; partially retract in sample | ; spotting G0 E0,0783 F25 ; first extrusion per spot G4 P300 ; waiting time on spot after extrusion G0 Z1,35 F100 G4 S1 G0 Z0,35 F100 G0 E0,0783 F25 G4 P300 G0 Z1,35 F100 G4 S1 G0 Z0,35 F100 G0 E0,0783 F25 G4 P300 G0 Z1,35 F100 G4 S1 G0 Z0,35 F100 G0 E0,0783 F25 G4 P300 G0 Z1,35 F100 G4 S1 G0 Z0,35 F100 G0 E0,0783 F25 G4 P300 G0 Z1,35 F100 G4 S1 G0 Z0,35 F100 G0 E0,0783 F25 G4 P300 G0 Z1,35 F100 G4 S1 G0 Z0,35 F100 G0 E0,0783 F25 G4 P300 G0 Z1,35 F100 G4 S1 G0 Z0,35 F100 G0 E0,0783 F25 G4 P300 G0 Z1,35 F100 G4 S1 G0 Z0,35 F100 G0 E0,0783 F25 G4 P300 G0 Z1,35 F100 G4 S1 G0 Z0,35 F100 G0 E0,0783 F25 G4 P300 | ; waste G0 Z3,5 F500 G0 X226 Y212 F20000 ; move to waste bin G0 Z2 F500 G0 E5 F2500 ; extrude rest of sample solution G4 P300 ; pause for 100ms
clean | waste2 | intermediate cleaning process | cleaning at start | cleaning at end
G0 Z3,5 F500 G0 X191 Y212 F20000 ; move to cleaning solution G0 Z0,05 F500 G0 E-16,1745 F500 ; retract | G0 Z3,5 F500 G0 X226 Y212 F20000 ; move to waste bin G0 Z2 F500 G0 E16,1745 F2500 ; extrude cleaning solution G4 P300 ;pause | G0 Z3,5 F500 G0 X191 Y212 F20000 ; move to cleaning solution G0 Z0,05 F500 G0 E-16,1745 F500 ; retract G0 Z3,5 F500 G0 X226 Y212 F20000 ; move to waste bin G0 Z2 F500 G0 E16,1745 F2500 ; extrude cleaning solution G4 P300 ;pause | ; cleaning at the start G0 Z3,5 F500 G0 X191 Y212 F20000 ; move to cleaning solution G0 Z0,05 F500 G0 E-16,1745 F500 ; retract G0 Z3,5 F500 G0 X226 Y212 F20000 ; move to waste bin G0 Z2 F500 G0 E16,1745 F2500 ; extrude cleaning solution G4 P300 ;pause G0 Z3,5 F500 G0 X191 Y212 F20000 ; move to cleaning solution G0 Z0,05 F500 G0 E-16,1745 F500 ; retract G0 Z3,5 F500 G0 X226 Y212 F20000 ; move to waste bin G0 Z2 F500 G0 E16,1745 F2500 ; extrude cleaning solution G4 P300 ;pause | ; cleaning at the end G0 Z3,5 F500 G0 X191 Y212 F20000 ; move to cleaning solution G0 Z0,05 F500 G0 E-16,1745 F500 ; retract G0 Z3,5 F500 G0 X226 Y212 F20000 ; move to waste bin G0 Z2 F500 G0 E16,1745 F2500 ; extrude cleaning solution G4 P300 ;pause G0 Z3,5 F500 G0 X191 Y212 F20000 ; move to cleaning solution G0 Z0,05 F500 G0 E-16,1745 F500 ; retract G0 Z3,5 F500 G0 X226 Y212 F20000 ; move to waste bin G0 Z2 F500 G0 E16,1745 F2500 ; extrude cleaning solution G4 P300 ;pause
calibration | washing (option: turning heating on at the start) | sound at the end
G0 X175,8 Y59 F20000 G0 Z0,9 F500 | G0 X191 Y212 F20000 ; move to cleaning solution G0 Z0,05 F500 G1 E-248 F900 ; fill syringe G4 S1 ; waiting time to fill syringe G1 E248 F10000 ; empty syringe G1 E-248 F900 G4 S1 G1 E248 F10000 G1 E-248 F900 G4 S1 G1 E248 F10000 | M300 S880 P75 M300 S0 P880 M300 S880 P75 M300 S0 P75 M300 S880 P75 M300 S0 P300 M300 S880 P75 M300 S0 P880 M300 S880 P75 M300 S0 P300 M300 S880 P75 M300 S0 P880 M300 S880 P75 M300 S0 P880 M300 S880 P75 M300 S0 P75 M300 S880 P75 M300 S0 P300 M300 S880 P75 M300 S0 P880 M300 S880 P75 M300 S0 P300 M300 S880 P75 M300 S0 P880 M300 S880 P75 M300 S0 P880 M300 S880 P75 M300 S0 P75 M300 S880 P75 M300 S0 P300 M300 S880 P75 M300 S0 P880 M300 S880 P75 M300 S0 P300 M300 S880 P75 M300 S0 P880
heating on | heating off | cold extrusion | wait for temperature
M104 S50 ; turn heating on | M104 S0 ; turn heating off | M302 S0 ; enable cold extrusion | M109 S50 ; wait for hotend temperature

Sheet: calc3
No. of samples | No. of spots | rack row | rack column | rack x | rack y | TLC x | TLC y | sample? | clean? | rack | TLC | cleaning process | g-code
1 | 1 | 1 | 0 | 0 | 295 | 297.3636364 | 122 | TRUE | TRUE | ; rack G0 Z3,5 F500 G0 X0 Y295 F20000 ; move to sample No. 1 G0 Z0,05 F500 | G0 Z3,5 F500 G0 X297,363636363636 Y122 F20000 ; move to spot No.1 G0 Z1,35 F500 ; decrease z-velocity for contact with TLC G0 Z0,35 F100 | ; cleaning process G0 Z3,5 F500 G0 X191 Y212 F20000 ; move to cleaning solution G0 Z0,05 F500 G0 E-16,1745 F500 ; retract G0 Z3,5 F500 G0 X226 Y212 F20000 ; move to waste bin G0 Z2 F500 G0 E16,1745 F2500 ; extrude cleaning solution G4 P300 ;pause | ; Spot No.1 ; rack G0 Z3,5 F500 G0 X0 Y295 F20000 ; move to sample No. 1 G0 Z0,05 F500 ; sampling G0 E-10,783 F500 ; extrusion in sample G0 E5 F500 ; partially retract in sample G0 Z3,5 F500 G0 X297,363636363636 Y122 F20000 ; move to spot No.1 G0 Z1,35 F500 ; decrease z-velocity for contact with TLC G0 Z0,35 F100 ; spotting G0 E0,0783 F25 ; first extrusion per spot G4 P300 ; waiting time on spot after extrusion G0 Z1,35 F100 G4 S1 G0 Z0,35 F100 G0 E0,0783 F25 G4 P300 G0 Z1,35 F100 G4 S1 G0 Z0,35 F100 G0 E0,0783 F25 G4 P300 G0 Z1,35 F100 G4 S1 G0 Z0,35 F100 G0 E0,0783 F25 G4 P300 G0 Z1,35 F100 G4 S1 G0 Z0,35 F100 G0 E0,0783 F25 G4 P300 G0 Z1,35 F100 G4 S1 G0 Z0,35 F100 G0 E0,0783 F25 G4 P300 G0 Z1,35 F100 G4 S1 G0 Z0,35 F100 G0 E0,0783 F25 G4 P300 G0 Z1,35 F100 G4 S1 G0 Z0,35 F100 G0 E0,0783 F25 G4 P300 G0 Z1,35 F100 G4 S1 G0 Z0,35 F100 G0 E0,0783 F25 G4 P300 G0 Z1,35 F100 G4 S1 G0 Z0,35 F100 G0 E0,0783 F25 G4 P300 ; waste G0 Z3,5 F500 G0 X226 Y212 F20000 ; move to waste bin G0 Z2 F500 G0 E5 F2500 ; extrude rest of sample solution G4 P300 ; pause for 100ms ; cleaning process G0 Z3,5 F500 G0 X191 Y212 F20000 ; move to cleaning solution G0 Z0,05 F500 G0 E-16,1745 F500 ; retract G0 Z3,5 F500 G0 X226 Y212 F20000 ; move to waste bin G0 Z2 F500 G0 E16,1745 F2500 ; extrude cleaning solution G4 P300 ;pause
2 | 2 | 1 | 1 | 0 | 262.8333333 | 293.7272727 | 122 | TRUE | TRUE | G0 Z3,5 F500 G0 X0 Y262,833333333333 F20000 ; move to sample No. 2 G0 Z0,05 F500 | G0 Z3,5 F500 G0 X293,727272727273 Y122 F20000 ; move to spot No.2 G0 Z1,35 F500 ; decrease z-velocity for contact with TLC G0 Z0,35 F100 | ; cleaning process G0 Z3,5 F500 G0 X191 Y212 F20000 ; move to cleaning solution G0 Z0,05 F500 G0 E-16,1745 F500 ; retract G0 Z3,5 F500 G0 X226 Y212 F20000 ; move to waste bin G0 Z2 F500 G0 E16,1745 F2500 ; extrude cleaning solution G4 P300 ;pause | ; Spot No.2 G0 Z3,5 F500 G0 X0 Y262,833333333333 F20000 ; move to sample No. 2 G0 Z0,05 F500 ; sampling G0 E-10,783 F500 ; extrusion in sample G0 E5 F500 ; partially retract in sample G0 Z3,5 F500 G0 X293,727272727273 Y122 F20000 ; move to spot No.2 G0 Z1,35 F500 ; decrease z-velocity for contact with TLC G0 Z0,35 F100 ; spotting G0 E0,0783 F25 ; first extrusion per spot G4 P300 ; waiting time on spot after extrusion G0 Z1,35 F100 G4 S1 G0 Z0,35 F100 G0 E0,0783 F25 G4 P300 G0 Z1,35 F100 G4 S1 G0 Z0,35 F100 G0 E0,0783 F25 G4 P300 G0 Z1,35 F100 G4 S1 G0 Z0,35 F100 G0 E0,0783 F25 G4 P300 G0 Z1,35 F100 G4 S1 G0 Z0,35 F100 G0 E0,0783 F25 G4 P300 G0 Z1,35 F100 G4 S1 G0 Z0,35 F100 G0 E0,0783 F25 G4 P300 G0 Z1,35 F100 G4 S1 G0 Z0,35 F100 G0 E0,0783 F25 G4 P300 G0 Z1,35 F100 G4 S1 G0 Z0,35 F100 G0 E0,0783 F25 G4 P300 G0 Z1,35 F100 G4 S1 G0 Z0,35 F100 G0 E0,0783 F25 G4 P300 G0 Z1,35 F100 G4 S1 G0 Z0,35 F100 G0 E0,0783 F25 G4 P300 ; waste G0 Z3,5 F500 G0 X226 Y212 F20000 ; move to waste bin G0 Z2 F500 G0 E5 F2500 ; extrude rest of sample solution G4 P300 ; pause for 100ms ; cleaning process G0 Z3,5 F500 G0 X191 Y212 F20000 ; move to cleaning solution G0 Z0,05 F500 G0 E-16,1745 F500 ; retract G0 Z3,5 F500 G0 X226 Y212 F20000 ; move to waste bin G0 Z2 F500 G0 E16,1745 F2500 ; extrude cleaning solution G4 P300 ;pause
3 | 3 | 1 | 2 | 0 | 230.6666667 | 290.0909091 | 122 | TRUE | TRUE | G0 Z3,5 F500 G0 X0 Y230,666666666667 F20000 ; move to sample No. 3 G0 Z0,05 F500 | G0 Z3,5 F500 G0 X290,090909090909 Y122 F20000 ; move to spot No.3 G0 Z1,35 F500 ; decrease z-velocity for contact with TLC G0 Z0,35 F100 | ; cleaning process G0 Z3,5 F500 G0 X191 Y212 F20000 ; move to cleaning solution G0 Z0,05 F500 G0 E-16,1745 F500 ; retract G0 Z3,5 F500 G0 X226 Y212 F20000 ; move to waste bin G0 Z2 F500 G0 E16,1745 F2500 ; extrude cleaning solution G4 P300 ;pause | ; Spot No.3 G0 Z3,5 F500 G0 X0 Y230,666666666667 F20000 ; move to sample No. 3 G0 Z0,05 F500 ; sampling G0 E-10,783 F500 ; extrusion in sample G0 E5 F500 ; partially retract in sample G0 Z3,5 F500 G0 X290,090909090909 Y122 F20000 ; move to spot No.3 G0 Z1,35 F500 ; decrease z-velocity for contact with TLC G0 Z0,35 F100 ; spotting G0 E0,0783 F25 ; first extrusion per spot G4 P300 ; waiting time on spot after extrusion G0 Z1,35 F100 G4 S1 G0 Z0,35 F100 G0 E0,0783 F25 G4 P300 G0 Z1,35 F100 G4 S1 G0 Z0,35 F100 G0 E0,0783 F25 G4 P300 G0 Z1,35 F100 G4 S1 G0 Z0,35 F100 G0 E0,0783 F25 G4 P300 G0 Z1,35 F100 G4 S1 G0 Z0,35 F100 G0 E0,0783 F25 G4 P300 G0 Z1,35 F100 G4 S1 G0 Z0,35 F100 G0 E0,0783 F25 G4 P300 G0 Z1,35 F100 G4 S1 G0 Z0,35 F100 G0 E0,0783 F25 G4 P300 G0 Z1,35 F100 G4 S1 G0 Z0,35 F100 G0 E0,0783 F25 G4 P300 G0 Z1,35 F100 G4 S1 G0 Z0,35 F100 G0 E0,0783 F25 G4 P300 G0 Z1,35 F100 G4 S1 G0 Z0,35 F100 G0 E0,0783 F25 G4 P300 ; waste G0 Z3,5 F500 G0 X226 Y212 F20000 ; move to waste bin G0 Z2 F500 G0 E5 F2500 ; extrude rest of sample solution G4 P300 ; pause for 100ms ; cleaning process G0 Z3,5 F500 G0 X191 Y212 F20000 ; move to cleaning solution G0 Z0,05 F500 G0 E-16,1745 F500 ; retract G0 Z3,5 F500 G0 X226 Y212 F20000 ; move to waste bin G0 Z2 F500 G0 E16,1745 F2500 ; extrude cleaning solution G4 P300 ;pause
4 | 4 | 1 | 3 | 0 | 198.5 | 286.4545455 | 122 | TRUE | TRUE | G0 Z3,5 F500 G0 X0 Y198,5 F20000 ; move to sample No. 4 G0 Z0,05 F500 | G0 Z3,5 F500 G0 X286,454545454545 Y122 F20000 ; move to spot No.4 G0 Z1,35 F500 ; decrease z-velocity for contact with TLC G0 Z0,35 F100 | ; cleaning process G0 Z3,5 F500 G0 X191 Y212 F20000 ; move to cleaning solution G0 Z0,05 F500 G0 E-16,1745 F500 ; retract G0 Z3,5 F500 G0 X226 Y212 F20000 ; move to waste bin G0 Z2 F500 G0 E16,1745 F2500 ; extrude cleaning solution G4 P300 ;pause | ; Spot No.4 G0 Z3,5 F500 G0 X0 Y198,5 F20000 ; move to sample No. 4 G0 Z0,05 F500 ; sampling G0 E-10,783 F500 ; extrusion in sample G0 E5 F500 ; partially retract in sample G0 Z3,5 F500 G0 X286,454545454545 Y122 F20000 ; move to spot No.4 G0 Z1,35 F500 ; decrease z-velocity for contact with TLC G0 Z0,35 F100 ; spotting G0 E0,0783 F25 ; first extrusion per spot G4 P300 ; waiting time on spot after extrusion G0 Z1,35 F100 G4 S1 G0 Z0,35 F100 G0 E0,0783 F25 G4 P300 G0 Z1,35 F100 G4 S1 G0 Z0,35 F100 G0 E0,0783 F25 G4 P300 G0 Z1,35 F100 G4 S1 G0 Z0,35 F100 G0 E0,0783 F25 G4 P300 G0 Z1,35 F100 G4 S1 G0 Z0,35 F100 G0 E0,0783 F25 G4 P300 G0 Z1,35 F100 G4 S1 G0 Z0,35 F100 G0 E0,0783 F25 G4 P300 G0 Z1,35 F100 G4 S1 G0 Z0,35 F100 G0 E0,0783 F25 G4 P300 G0 Z1,35 F100 G4 S1 G0 Z0,35 F100 G0 E0,0783 F25 G4 P300 G0 Z1,35 F100 G4 S1 G0 Z0,35 F100 G0 E0,0783 F25 G4 P300 G0 Z1,35 F100 G4 S1 G0 Z0,35 F100 G0 E0,0783 F25 G4 P300 ; waste G0 Z3,5 F500 G0 X226 Y212 F20000 ; move to waste bin G0 Z2 F500 G0 E5 F2500 ; extrude rest of sample solution G4 P300 ; pause for 100ms ; cleaning process G0 Z3,5 F500 G0 X191 Y212 F20000 ; move to cleaning solution G0 Z0,05 F500 G0 E-16,1745 F500 ; retract G0 Z3,5 F500 G0 X226 Y212 F20000 ; move to waste bin G0 Z2 F500 G0 E16,1745 F2500 ; extrude cleaning solution G4 P300 ;pause
5 | 5 | 1 | 4 | 0 | 166.3333333 | 282.8181818 | 122 | TRUE | TRUE | G0 Z3,5 F500 G0 X0 Y166,333333333333 F20000 ; move to sample No. 5 G0 Z0,05 F500 | G0 Z3,5 F500 G0 X282,818181818182 Y122 F20000 ; move to spot No.5 G0 Z1,35 F500 ; decrease z-velocity for contact with TLC G0 Z0,35 F100 | ; cleaning process G0 Z3,5 F500 G0 X191 Y212 F20000 ; move to cleaning solution G0 Z0,05 F500 G0 E-16,1745 F500 ; retract G0 Z3,5 F500 G0 X226 Y212 F20000 ; move to waste bin G0 Z2 F500 G0 E16,1745 F2500 ; extrude cleaning solution G4 P300 ;pause | ; Spot No.5 G0 Z3,5 F500 G0 X0 Y166,333333333333 F20000 ; move to sample No. 5 G0 Z0,05 F500 ; sampling G0 E-10,783 F500 ; extrusion in sample G0 E5 F500 ; partially retract in sample G0 Z3,5 F500 G0 X282,818181818182 Y122 F20000 ; move to spot No.5 G0 Z1,35 F500 ; decrease z-velocity for contact with TLC G0 Z0,35 F100 ; spotting G0 E0,0783 F25 ; first extrusion per spot G4 P300 ; waiting time on spot after extrusion G0 Z1,35 F100 G4 S1 G0 Z0,35 F100 G0 E0,0783 F25 G4 P300 G0 Z1,35 F100 G4 S1 G0 Z0,35 F100 G0 E0,0783 F25 G4 P300 G0 Z1,35 F100 G4 S1 G0 Z0,35 F100 G0 E0,0783 F25 G4 P300 G0 Z1,35 F100 G4 S1 G0 Z0,35 F100 G0 E0,0783 F25 G4 P300 G0 Z1,35 F100 G4 S1 G0 Z0,35 F100 G0 E0,0783 F25 G4 P300 G0 Z1,35 F100 G4 S1 G0 Z0,35 F100 G0 E0,0783 F25 G4 P300 G0 Z1,35 F100 G4 S1 G0 Z0,35 F100 G0 E0,0783 F25 G4 P300 G0 Z1,35 F100 G4 S1 G0 Z0,35 F100 G0 E0,0783 F25 G4 P300 G0 Z1,35 F100 G4 S1 G0 Z0,35 F100 G0 E0,0783 F25 G4 P300 ; waste G0 Z3,5 F500 G0 X226 Y212 F20000 ; move to waste bin G0 Z2 F500 G0 E5 F2500 ; extrude rest of sample solution G4 P300 ; pause for 100ms ; cleaning process G0 Z3,5 F500 G0 X191 Y212 F20000 ; move to cleaning solution G0 Z0,05 F500 G0 E-16,1745 F500 ; retract G0 Z3,5 F500 G0 X226 Y212 F20000 ; move to waste bin G0 Z2 F500 G0 E16,1745 F2500 ; extrude cleaning solution G4 P300 ;pause
6 | 6 | 1 | 5 | 0 | 134.1666667 | 279.1818182 | 122 | TRUE | TRUE | G0 Z3,5 F500 G0 X0 Y134,166666666667 F20000 ; move to sample No. 6 G0 Z0,05 F500 | G0 Z3,5 F500 G0 X279,181818181818 Y122 F20000 ; move to spot No.6 G0 Z1,35 F500 ; decrease z-velocity for contact with TLC G0 Z0,35 F100 | ; cleaning process G0 Z3,5 F500 G0 X191 Y212 F20000 ; move to cleaning solution G0 Z0,05 F500 G0 E-16,1745 F500 ; retract G0 Z3,5 F500 G0 X226 Y212 F20000 ; move to waste bin G0 Z2 F500 G0 E16,1745 F2500 ; extrude cleaning solution G4 P300 ;pause | ; Spot No.6 G0 Z3,5 F500 G0 X0 Y134,166666666667 F20000 ; move to sample No. 6 G0 Z0,05 F500 ; sampling G0 E-10,783 F500 ; extrusion in sample G0 E5 F500 ; partially retract in sample G0 Z3,5 F500 G0 X279,181818181818 Y122 F20000 ; move to spot No.6 G0 Z1,35 F500 ; decrease z-velocity for contact with TLC G0 Z0,35 F100 ; spotting G0 E0,0783 F25 ; first extrusion per spot G4 P300 ; waiting time on spot after extrusion G0 Z1,35 F100 G4 S1 G0 Z0,35 F100 G0 E0,0783 F25 G4 P300 G0 Z1,35 F100 G4 S1 G0 Z0,35 F100 G0 E0,0783 F25 G4 P300 G0 Z1,35 F100 G4 S1 G0 Z0,35 F100 G0 E0,0783 F25 G4 P300 G0 Z1,35 F100 G4 S1 G0 Z0,35 F100 G0 E0,0783 F25 G4 P300 G0 Z1,35 F100 G4 S1 G0 Z0,35 F100 G0 E0,0783 F25 G4 P300 G0 Z1,35 F100 G4 S1 G0 Z0,35 F100 G0 E0,0783 F25 G4 P300 G0 Z1,35 F100 G4 S1 G0 Z0,35 F100 G0 E0,0783 F25 G4 P300 G0 Z1,35 F100 G4 S1 G0 Z0,35 F100 G0 E0,0783 F25 G4 P300 G0 Z1,35 F100 G4 S1 G0 Z0,35 F100 G0 E0,0783 F25 G4 P300 ; waste G0 Z3,5 F500 G0 X226 Y212 F20000 ; move to waste bin G0 Z2 F500 G0 E5 F2500 ; extrude rest of sample solution G4 P300 ; pause for 100ms ; cleaning process G0 Z3,5 F500 G0 X191 Y212 F20000 ; move to cleaning solution G0 Z0,05 F500 G0 E-16,1745 F500 ; retract G0 Z3,5 F500 G0 X226 Y212 F20000 ; move to waste bin G0 Z2 F500 G0 E16,1745 F2500 ; extrude cleaning solution G4 P300 ;pause
7 | 7 | 1 | 6 | 0 | 102 | 275.5454545 | 122 | TRUE | TRUE | G0 Z3,5 F500 G0 X0 Y102 F20000 ; move to sample No. 7 G0 Z0,05 F500 | G0 Z3,5 F500 G0 X275,545454545455 Y122 F20000 ; move to spot No.7 G0 Z1,35 F500 ; decrease z-velocity for contact with TLC G0 Z0,35 F100 | ; cleaning process G0 Z3,5 F500 G0 X191 Y212 F20000 ; move to cleaning solution G0 Z0,05 F500 G0 E-16,1745 F500 ; retract G0 Z3,5 F500 G0 X226 Y212 F20000 ; move to waste bin G0 Z2 F500 G0 E16,1745 F2500 ; extrude cleaning solution G4 P300 ;pause | ; Spot No.7 G0 Z3,5 F500 G0 X0 Y102 F20000 ; move to sample No. 7 G0 Z0,05 F500 ; sampling G0 E-10,783 F500 ; extrusion in sample G0 E5 F500 ; partially retract in sample G0 Z3,5 F500 G0 X275,545454545455 Y122 F20000 ; move to spot No.7 G0 Z1,35 F500 ; decrease z-velocity for contact with TLC G0 Z0,35 F100 ; spotting G0 E0,0783 F25 ; first extrusion per spot G4 P300 ; waiting time on spot after extrusion G0 Z1,35 F100 G4 S1 G0 Z0,35 F100 G0 E0,0783 F25 G4 P300 G0 Z1,35 F100 G4 S1 G0 Z0,35 F100 G0 E0,0783 F25 G4 P300 G0 Z1,35 F100 G4 S1 G0 Z0,35 F100 G0 E0,0783 F25 G4 P300 G0 Z1,35 F100 G4 S1 G0 Z0,35 F100 G0 E0,0783 F25 G4 P300 G0 Z1,35 F100 G4 S1 G0 Z0,35 F100 G0 E0,0783 F25 G4 P300 G0 Z1,35 F100 G4 S1 G0 Z0,35 F100 G0 E0,0783 F25 G4 P300 G0 Z1,35 F100 G4 S1 G0 Z0,35 F100 G0 E0,0783 F25 G4 P300 G0 Z1,35 F100 G4 S1 G0 Z0,35 F100 G0 E0,0783 F25 G4 P300 G0 Z1,35 F100 G4 S1 G0 Z0,35 F100 G0 E0,0783 F25 G4 P300 ; waste G0 Z3,5 F500 G0 X226 Y212 F20000 ; move to waste bin G0 Z2 F500 G0 E5 F2500 ; extrude rest of sample solution G4 P300 ; pause for 100ms ; cleaning process G0 Z3,5 F500 G0 X191 Y212 F20000 ; move to cleaning solution G0 Z0,05 F500 G0 E-16,1745 F500 ; retract G0 Z3,5 F500 G0 X226 Y212 F20000 ; move to waste bin G0 Z2 F500 G0 E16,1745 F2500 ; extrude cleaning solution G4 P300 ;pause
8 | 8 | 2 | 0 | 40.5 | 102 | 271.9090909 | 122 | TRUE | TRUE | G0 Z3,5 F500 G0 X40,5 Y102 F20000 ; move to sample No. 8 G0 Z0,05 F500 | G0 Z3,5 F500 G0 X271,909090909091 Y122 F20000 ; move to spot No.8 G0 Z1,35 F500 ; decrease z-velocity for contact with TLC G0 Z0,35 F100 | ; cleaning process G0 Z3,5 F500 G0 X191 Y212 F20000 ; move to cleaning solution G0 Z0,05 F500 G0 E-16,1745 F500 ; retract G0 Z3,5 F500 G0 X226 Y212 F20000 ; move to waste bin G0 Z2 F500 G0 E16,1745 F2500 ; extrude cleaning solution G4 P300 ;pause | ; Spot No.8 G0 Z3,5 F500 G0 X40,5 Y102 F20000 ; move to sample No. 8 G0 Z0,05 F500 ; sampling G0 E-10,783 F500 ; extrusion in sample G0 E5 F500 ; partially retract in sample G0 Z3,5 F500 G0 X271,909090909091 Y122 F20000 ; move to spot No.8 G0 Z1,35 F500 ; decrease z-velocity for contact with TLC G0 Z0,35 F100 ; spotting G0 E0,0783 F25 ; first extrusion per spot G4 P300 ; waiting time on spot after extrusion G0 Z1,35 F100 G4 S1 G0 Z0,35 F100 G0 E0,0783 F25 G4 P300 G0 Z1,35 F100 G4 S1 G0 Z0,35 F100 G0 E0,0783 F25 G4 P300 G0 Z1,35 F100 G4 S1 G0 Z0,35 F100 G0 E0,0783 F25 G4 P300 G0 Z1,35 F100 G4 S1 G0 Z0,35 F100 G0 E0,0783 F25 G4 P300 G0 Z1,35 F100 G4 S1 G0 Z0,35 F100 G0 E0,0783 F25 G4 P300 G0 Z1,35 F100 G4 S1 G0 Z0,35 F100 G0 E0,0783 F25 G4 P300 G0 Z1,35 F100 G4 S1 G0 Z0,35 F100 G0 E0,0783 F25 G4 P300 G0 Z1,35 F100 G4 S1 G0 Z0,35 F100 G0 E0,0783 F25 G4 P300 G0 Z1,35 F100 G4 S1 G0 Z0,35 F100 G0 E0,0783 F25 G4 P300 ; waste G0 Z3,5 F500 G0 X226 Y212 F20000 ; move to waste bin G0 Z2 F500 G0 E5 F2500 ; extrude rest of sample solution G4 P300 ; pause for 100ms ; cleaning process G0 Z3,5 F500 G0 X191 Y212 F20000 ; move to cleaning solution G0 Z0,05 F500 G0 E-16,1745 F500 ; retract G0 Z3,5 F500 G0 X226 Y212 F20000 ; move to waste bin G0 Z2 F500 G0 E16,1745 F2500 ; extrude cleaning solution G4 P300 ;pause
9 | 9 | 2 | 1 | 40.5 | 134.1666667 | 268.2727273 | 122 | TRUE | TRUE | G0 Z3,5 F500 G0 X40,5 Y134,166666666667 F20000 ; move to sample No. 9 G0 Z0,05 F500 | G0 Z3,5 F500 G0 X268,272727272727 Y122 F20000 ; move to spot No.9 G0 Z1,35 F500 ; decrease z-velocity for contact with TLC G0 Z0,35 F100 | ; cleaning process G0 Z3,5 F500 G0 X191 Y212 F20000 ; move to cleaning solution G0 Z0,05 F500 G0 E-16,1745 F500 ; retract G0 Z3,5 F500 G0 X226 Y212 F20000 ; move to waste bin G0 Z2 F500 G0 E16,1745 F2500 ; extrude cleaning solution G4 P300 ;pause | ; Spot No.9 G0 Z3,5 F500 G0 X40,5 Y134,166666666667 F20000 ; move to sample No. 9 G0 Z0,05 F500 ; sampling G0 E-10,783 F500 ; extrusion in sample G0 E5 F500 ; partially retract in sample G0 Z3,5 F500 G0 X268,272727272727 Y122 F20000 ; move to spot No.9 G0 Z1,35 F500 ; decrease z-velocity for contact with TLC G0 Z0,35 F100 ; spotting G0 E0,0783 F25 ; first extrusion per spot G4 P300 ; waiting time on spot after extrusion G0 Z1,35 F100 G4 S1 G0 Z0,35 F100 G0 E0,0783 F25 G4 P300 G0 Z1,35 F100 G4 S1 G0 Z0,35 F100 G0 E0,0783 F25 G4 P300 G0 Z1,35 F100 G4 S1 G0 Z0,35 F100 G0 E0,0783 F25 G4 P300 G0 Z1,35 F100 G4 S1 G0 Z0,35 F100 G0 E0,0783 F25 G4 P300 G0 Z1,35 F100 G4 S1 G0 Z0,35 F100 G0 E0,0783 F25 G4 P300 G0 Z1,35 F100 G4 S1 G0 Z0,35 F100 G0 E0,0783 F25 G4 P300 G0 Z1,35 F100 G4 S1 G0 Z0,35 F100 G0 E0,0783 F25 G4 P300 G0 Z1,35 F100 G4 S1 G0 Z0,35 F100 G0 E0,0783 F25 G4 P300 G0 Z1,35 F100 G4 S1 G0 Z0,35 F100 G0 E0,0783 F25 G4 P300 ; waste G0 Z3,5 F500 G0 X226 Y212 F20000 ; move to waste bin G0 Z2 F500 G0 E5 F2500 ; extrude rest of sample solution G4 P300 ; pause for 100ms ; cleaning process G0 Z3,5 F500 G0 X191 Y212 F20000 ; move to cleaning solution G0 Z0,05 F500 G0 E-16,1745 F500 ; retract G0 Z3,5 F500 G0 X226 Y212 F20000 ; move to waste bin G0 Z2 F500 G0 E16,1745 F2500 ; extrude cleaning solution G4 P300 ;pause
10 | 10 | 2 | 2 | 40.5 | 166.3333333 | 264.6363636 | 122 | TRUE | TRUE | G0 Z3,5 F500 G0 X40,5 Y166,333333333333 F20000 ; move to sample No. 10 G0 Z0,05 F500 | G0 Z3,5 F500 G0 X264,636363636364 Y122 F20000 ; move to spot No.10 G0 Z1,35 F500 ; decrease z-velocity for contact with TLC G0 Z0,35 F100 | ; cleaning process G0 Z3,5 F500 G0 X191 Y212 F20000 ; move to cleaning solution G0 Z0,05 F500 G0 E-16,1745 F500 ; retract G0 Z3,5 F500 G0 X226 Y212 F20000 ; move to waste bin G0 Z2 F500 G0 E16,1745 F2500 ; extrude cleaning solution G4 P300 ;pause | ; Spot No.10 G0 Z3,5 F500 G0 X40,5 Y166,333333333333 F20000 ; move to sample No. 10 G0 Z0,05 F500 ; sampling G0 E-10,783 F500 ; extrusion in sample G0 E5 F500 ; partially retract in sample G0 Z3,5 F500 G0 X264,636363636364 Y122 F20000 ; move to spot No.10 G0 Z1,35 F500 ; decrease z-velocity for contact with TLC G0 Z0,35 F100 ; spotting G0 E0,0783 F25 ; first extrusion per spot G4 P300 ; waiting time on spot after extrusion G0 Z1,35 F100 G4 S1 G0 Z0,35 F100 G0 E0,0783 F25 G4 P300 G0 Z1,35 F100 G4 S1 G0 Z0,35 F100 G0 E0,0783 F25 G4 P300 G0 Z1,35 F100 G4 S1 G0 Z0,35 F100 G0 E0,0783 F25 G4 P300 G0 Z1,35 F100 G4 S1 G0 Z0,35 F100 G0 E0,0783 F25 G4 P300 G0 Z1,35 F100 G4 S1 G0 Z0,35 F100 G0 E0,0783 F25 G4 P300 G0 Z1,35 F100 G4 S1 G0 Z0,35 F100 G0 E0,0783 F25 G4 P300 G0 Z1,35 F100 G4 S1 G0 Z0,35 F100 G0 E0,0783 F25 G4 P300 G0 Z1,35 F100 G4 S1 G0 Z0,35 F100 G0 E0,0783 F25 G4 P300 G0 Z1,35 F100 G4 S1 G0 Z0,35 F100 G0 E0,0783 F25 G4 P300 ; waste G0 Z3,5 F500 G0 X226 Y212 F20000 ; move to waste bin G0 Z2 F500 G0 E5 F2500 ; extrude rest of sample solution G4 P300 ; pause for 100ms ; cleaning process G0 Z3,5 F500 G0 X191 Y212 F20000 ; move to cleaning solution G0 Z0,05 F500 G0 E-16,1745 F500 ; retract G0 Z3,5 F500 G0 X226 Y212 F20000 ; move to waste bin G0 Z2 F500 G0 E16,1745 F2500 ; extrude cleaning solution G4 P300 ;pause
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

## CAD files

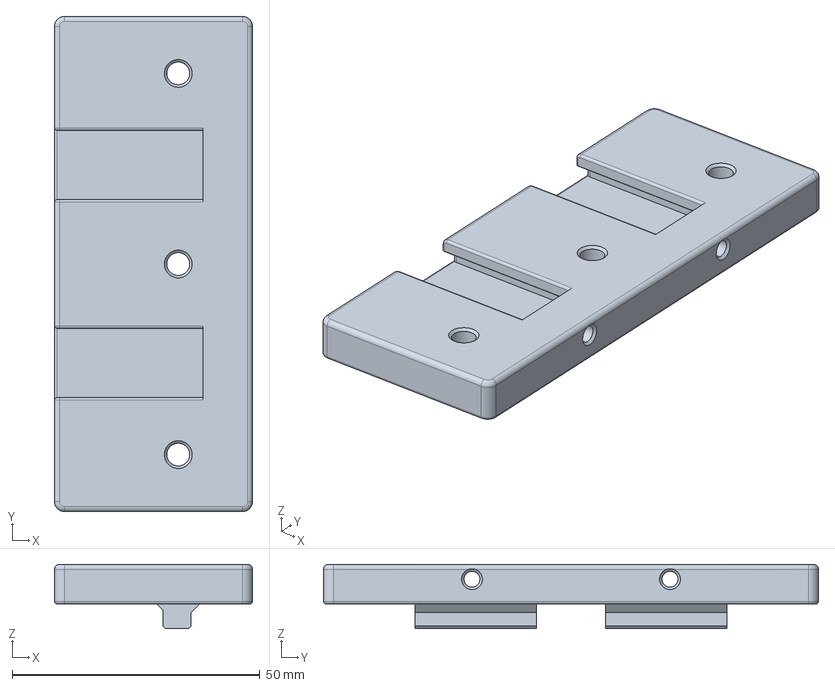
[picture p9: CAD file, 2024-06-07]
CAD files/10_BT_main.stp
40.0 x 100.0 x 13.0 mm

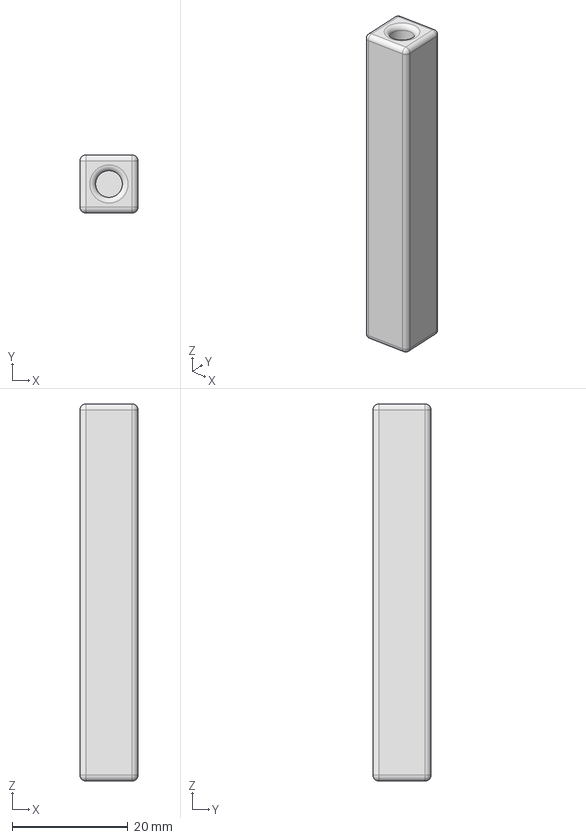
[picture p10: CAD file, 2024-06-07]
CAD files/14_TH_Leg.stp
10.0 x 10.0 x 65.0 mm

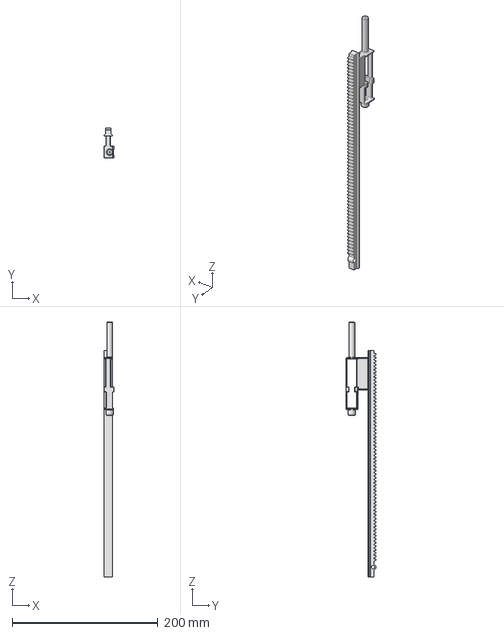
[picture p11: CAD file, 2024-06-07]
CAD files/03_Z_Gear_Rack.stp
14.0 x 41.7 x 350.0 mm

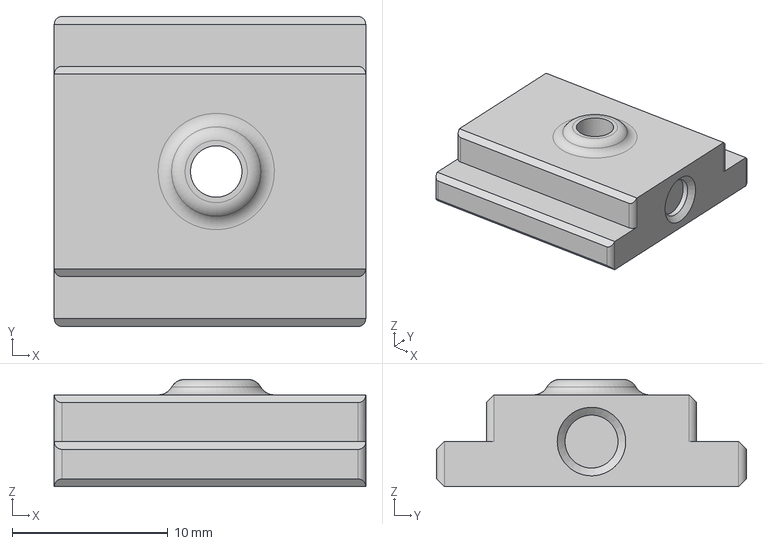
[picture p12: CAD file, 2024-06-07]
CAD files/12_BT_right.stp
20.0 x 19.9 x 6.90 mm

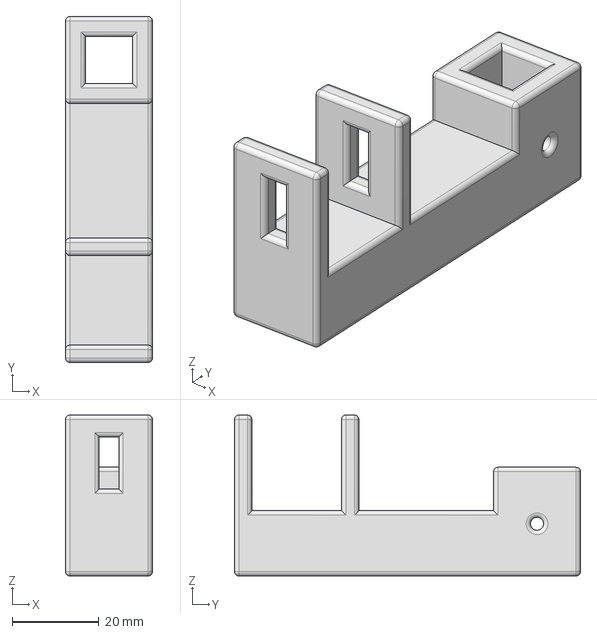
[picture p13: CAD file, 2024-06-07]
CAD files/18_PS_TH_X.stp
20.0 x 79.6 x 37.0 mm

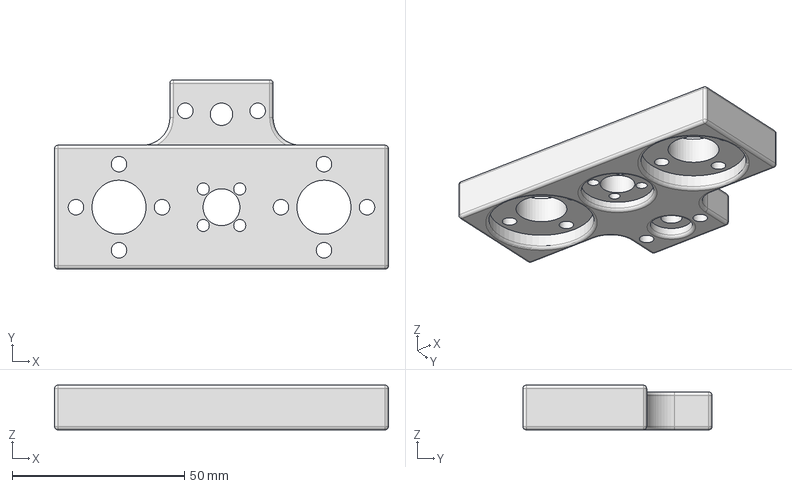
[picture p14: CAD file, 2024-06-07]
CAD files/05_SP_Middle.stp
97.0 x 55.0 x 13.0 mm

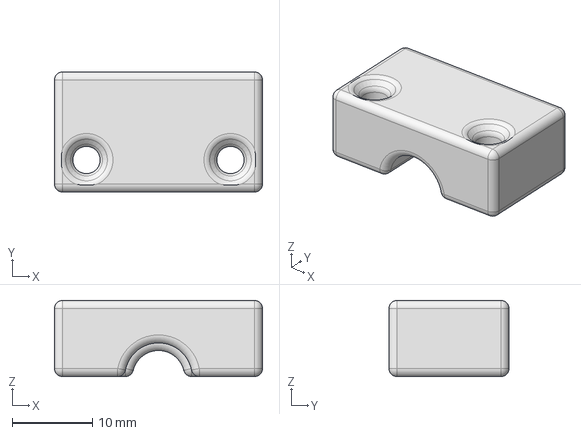
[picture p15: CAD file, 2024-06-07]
CAD files/08_SP_Clamp2.stp
26.0 x 15.0 x 9.50 mm

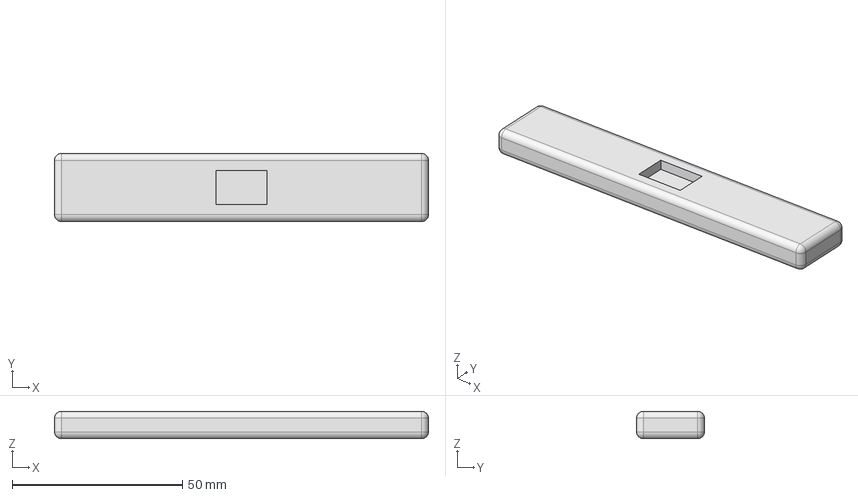
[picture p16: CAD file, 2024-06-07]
CAD files/15_TH_Plate.stp
110.0 x 20.0 x 8.00 mm

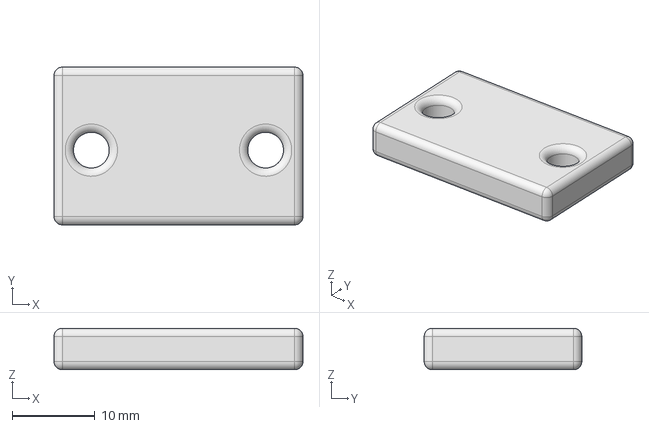
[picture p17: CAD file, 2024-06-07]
CAD files/09_SP_Plate.stp
30.0 x 19.0 x 5.00 mm

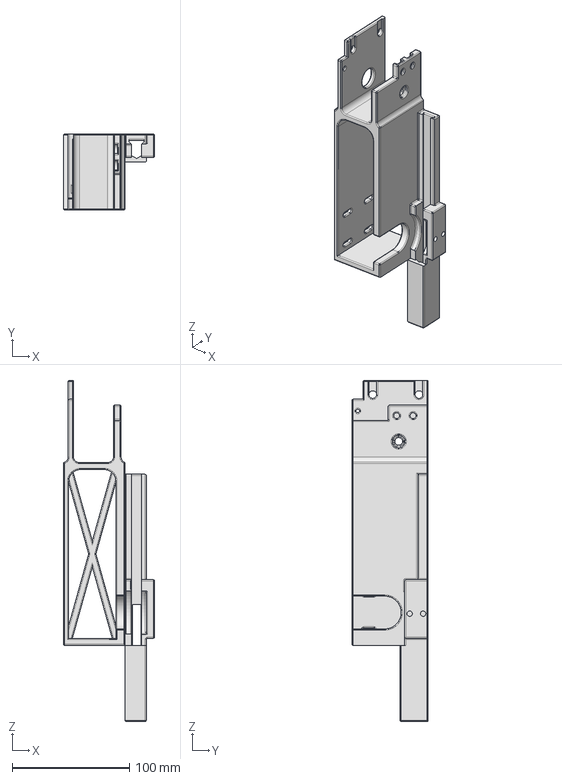
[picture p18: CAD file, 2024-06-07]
CAD files/01_Z_Mounting.stp
77.7 x 65.0 x 291.0 mm

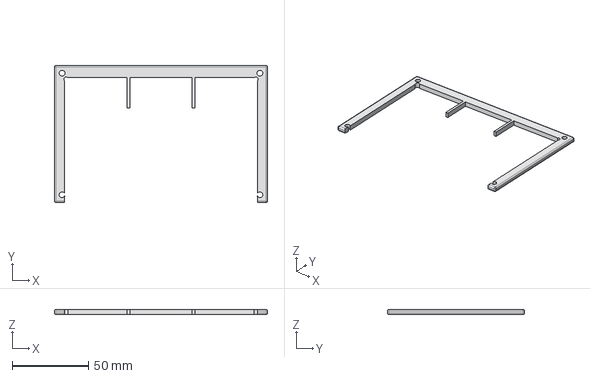
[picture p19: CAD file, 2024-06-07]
CAD files/13_TH_Top.stp
140.0 x 90.0 x 3.50 mm

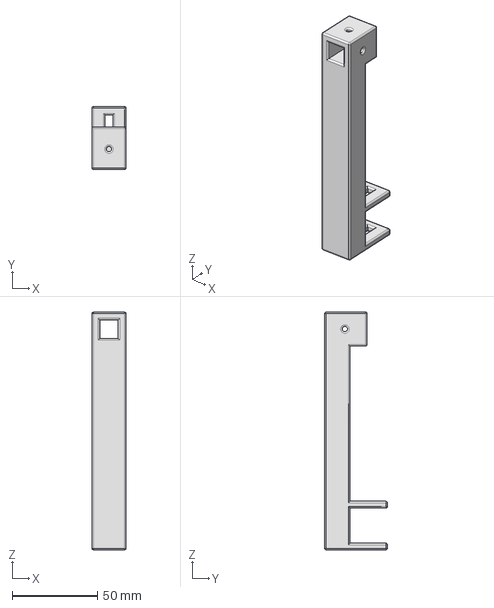
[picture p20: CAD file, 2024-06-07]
CAD files/19_PS_Table_X.stp
20.0 x 37.0 x 139.6 mm

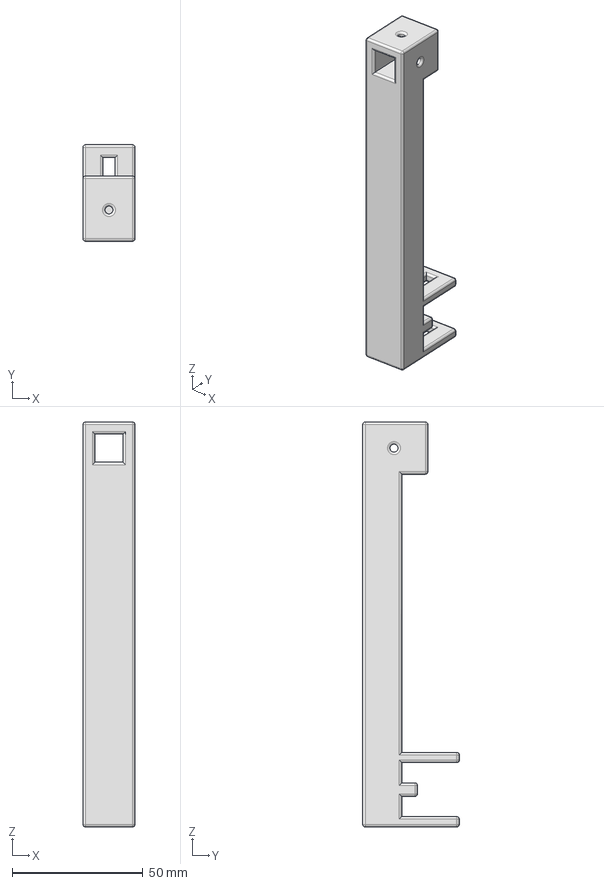
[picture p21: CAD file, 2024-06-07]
CAD files/20_PS_TH_Y.stp
20.0 x 37.0 x 155.0 mm

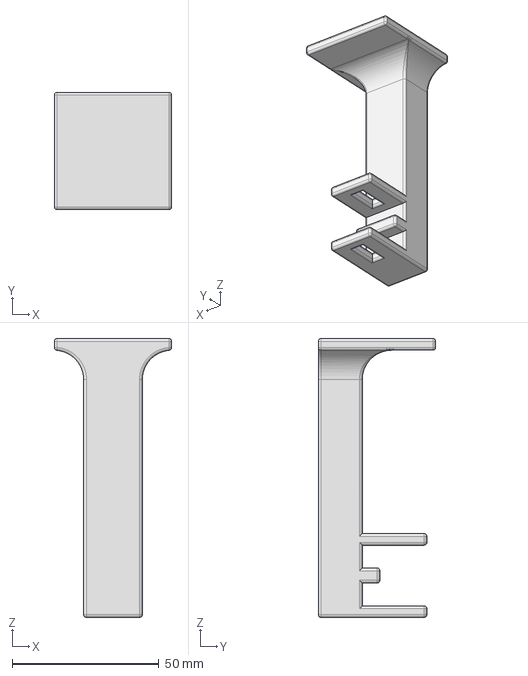
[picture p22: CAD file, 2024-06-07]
CAD files/16_PS_Rack_Y.stp
40.0 x 40.0 x 95.0 mm

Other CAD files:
CAD files/02_Z_Gear_Wheel.stp
CAD files/21_Table.stp
CAD files/06_SP_Bottom.stp
CAD files/17_PS_Rack_X.stp
CAD files/01_Z_Mounting.stl
CAD files/02_Z_Gear_Wheel.stl
CAD files/03.2_Z_Gear_Fixation.stl
CAD files/03.2_Z_Gear_Fixation.stp
CAD files/03_Z_Gear_Rack.stl
CAD files/04_SP_Top.stl
CAD files/04_SP_Top.stp
CAD files/05_SP_Middle.stl
CAD files/06_SP_Bottom.stl
CAD files/07_SP_Clamp1.stl
CAD files/07_SP_Clamp1.stp
CAD files/08_SP_Clamp2.stl
CAD files/09_SP_Plate.stl
CAD files/10_BT_main.stl
CAD files/11_BT_left.stl
CAD files/11_BT_left.stp
CAD files/12_BT_right.stl
CAD files/13_TH_Top.stl
CAD files/14_TH_Leg.stl
CAD files/15_TH_Plate.stl
CAD files/16_PS_Rack_Y.stl
CAD files/17_PS_Rack_X.stl
CAD files/18_PS_TH_X.stl
CAD files/19_PS_Table_X.stl
CAD files/20_PS_TH_Y.stl
CAD files/21_Table.stl
